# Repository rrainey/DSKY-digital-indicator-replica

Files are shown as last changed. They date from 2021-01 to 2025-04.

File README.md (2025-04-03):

# DSKY Digital Panel Replica

This is a scale functional replica of the Digital Indicator panel for the Apollo Guidance Computer. It is
designed to be part of a larger replica of the Display and Keyboard (DSKY) module of the AGC.

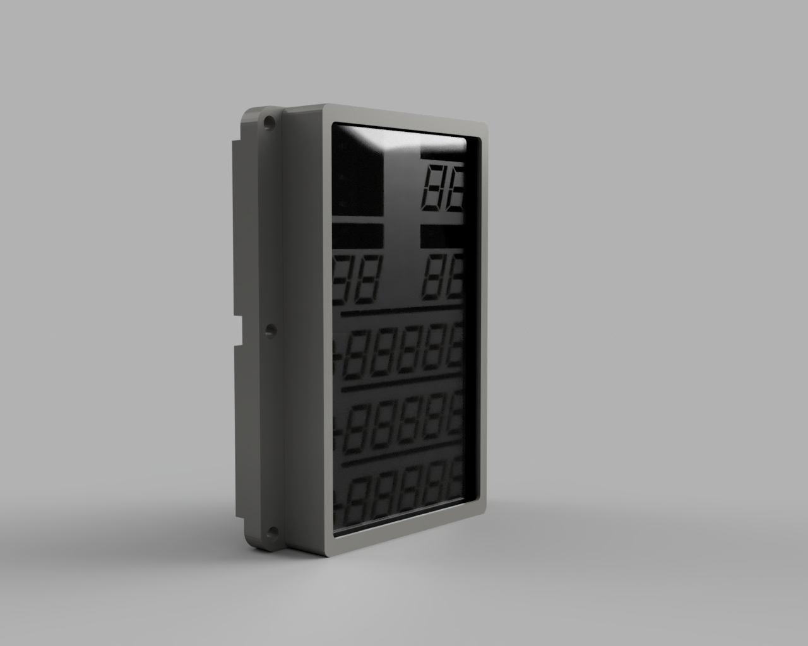
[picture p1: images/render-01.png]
See through view


This project is composed of these component subfolders:

* **artwork** - artwork to be printed or silk-screened onto the glass/acrylic cover.

* **pcb** - KiCad 9 project for the controller PCB design.

* **firmware** - Arduino-based controller firmware.  This module is designed to be controlled via the USB serial interface.

* **hardware** - 3D-printable frame components designed using Fusion 360. STEP and Fusion source files available. Hardware models used in thie replica were derived from models that are part of in the [AGC Mechanical CAD project](https://github.com/rrainey/agc-mechanical-cad).

## Bill of Materials

|  Part | Grainger Part | MFR Part  | QTY | Description |
|---|:---:|---|:-----:|---|
|  M2.5-0.45 Brass Insert| [1GNL7](https://www.grainger.com/product/Heat-Set-Insert-M2-5-0-45-1GNL7?searchQuery=1GNL7&searchBar=true) |  TH-M25-SV-PK100 | 4 | Brass inserts (sold as 100 pack) |
|  M2.5 x 6mm Screw | [6HB66](https://www.grainger.com/product/Machine-Screw-M2-5-Thread-6HB66) |  MPFD025060-100P1 | 4 | Machine screw: M2.5 Thread Size, 6 mm Lg, Steel, Zinc Plated, Flat, Phillips, Metric (sold as 100 pack) |
| Body | - | - | 1 | 3D Printable part |
| Retainer | - | - | 1 | 3D Printable part |
| Light Guide | - | - | 1 | CNC or 3D Printable part |
| PCB to Light Guide Adapter | - | - | 1 | 3D Printable part |
| Indicator face | - | - | 1 | Paper Printable part |

Models for all printable parts are located in the hardware subfolder.

## Interfaces

* USB 2.0 Micro-B port
* J-LINK-compatible SWD debugging interface (10-pin header)
* Power: +3.3VDC via a 4-pin header (2.1A maximum (estimated; software limited to 0.5A))

## Printed Circuit Board

Summary below. You will find more detailed notes in the [./pcb folder](./pcb/PCB-NOTES.md).

As of March 2025, V7 of the PCB design is current. Gerber and component placement files -- all generated by KiCad 7, are included in this repository.  [PCBWay](https://pcbway.com) generously sponsored this version of the project. If you are building one of these boards, you should consider them for either PCB fabrication or full-up PCB assembly.

I often use a solder reflow oven in my shop. I used PCBWay for full PCBA services on this latest version, but with the earlier boards - I assembled them myself using a [two step process](https://www.instructables.com/Making-double-side-boards-in-reflow-oven/) to first reflow the back (LED) side using Sn63/Pb37 paste, then reflow the front side using a lower temperature solder paste (Bi57Sn42Ag1).  

## Painting

The original NASA drawings for all variants of this component, [1006387D for example,](https://archive.org/stream/apertureCardBox439Part2NARASW_images#page/n409/mode/1up) point to [this NASA paint specification [1008809-1]](https://archive.org/stream/apertureCardBox443NARASW_images#page/n504/mode/1up). It states [FED-STD 36231](http://federalstandard595.com/36231/) as the external color of the unit.  Good quality historial photos (examples [here](https://www.icollector.com/Apollo-CM-DSKY_i21861898) and [here](http://nassp.sourceforge.net/wiki/File:DSKY.jpg)) seem to imply a slightly different shade of gray, though. 

I may custom mix using Nazdar pigments, or I might simply use [an aircraft-grade epoxy premix](https://www.skygeek.com/deft-01-series-epoxy-topcoat-gray-36231-mil-prf-227750g.html) of FS36231. For now, I am simply using Krylon brand [Ultra Matte Finish - 4102 Misty Gray](https://www.google.com/search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) paint.

## Credits and Related Projects

This project is inspired by work by Ben Krasnow creating a DSKY Electroluminescent Panel replica. You'll
find information about that project in [this Applied Science video](https://www.youtube.com/watch?v=Z2o_Sp2-aBo) by Ben. Like Ben's E/L display, this project is driven by an AT SAMD21 microcontroller chip; the same chip is used in the multiple Adafruit microcontroller boards, including the Adafruit Trinket M0.

## DSKY Digital Indicator License

Creative Commons Attribution/Share-Alike, all text above must be included in any redistribution. See license.txt for additional details.

## My Background

My name is Riley Rainey. I'm a software developer by profession. I spent a number of years building aerospace simulations as my day job.

## Getting Support

There's no official support available, but you can [leave comments or create an issue](https://github.com/rrainey/DSKY-digital-indicator-replica/issues) in this GitHub project.

  
This work is licensed under a [Creative Commons Attribution-ShareAlike 4.0 International License](http://creativecommons.org/licenses/by-sa/4.0/).

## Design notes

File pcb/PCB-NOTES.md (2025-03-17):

# PCB Fabrication and Assembly Notes

V7 of the PCB is the current version.  PCBWay generously offered to sponsor me on this latest version of the board. I supplied these parameters during the PCB manufacturing process:

| Parameter | Value |
|---|---|
| Material	| FR-4 TG150 |
| Size	| 105.5 x 63.5 mm |
| Layers |	4 |
| Thickness	| 1.6 mm	|
| Min Track/Spacing	| 8/8mil |
| Min Hole Size	 | 0.3 mm	 |
| Solder Mask	| Green	|
| Silkscreen	| White |
| Surface Finish |	ENIG - Immersion gold 1U"
| Via Process	| Tenting vias |
| Finished Copper	(outer layers) | 2 oz Cu |
| Inner Copper	| 1 oz Cu |	
| Gold Fingers	| No	|
| "HASL"to"ENIG" |	No |

If you are planning to assemble the board yourself, I'd suggest using a 0.1mm stainless steel solder stencil along with Type4 or Type 5 solder paste.  I did just that in my early prototypes and, given the small footprint of the TI LED driver ICs, this made laying down the solder for the reflow process much more reliable.

## Assembly

I used a reflow oven to solder components to the boards. I expect it would be difficult to hand solder the TI ICs. 

I populated the front (IC component) side of the board first using Pb 63/Sn 37 solder paste. I used low-temperature Bi/Sn solder for the back (LED) side.  This allowed me to used a lower temperature reflow profile for the back -- insuring the front components remained in-place during the reflow of the second side.

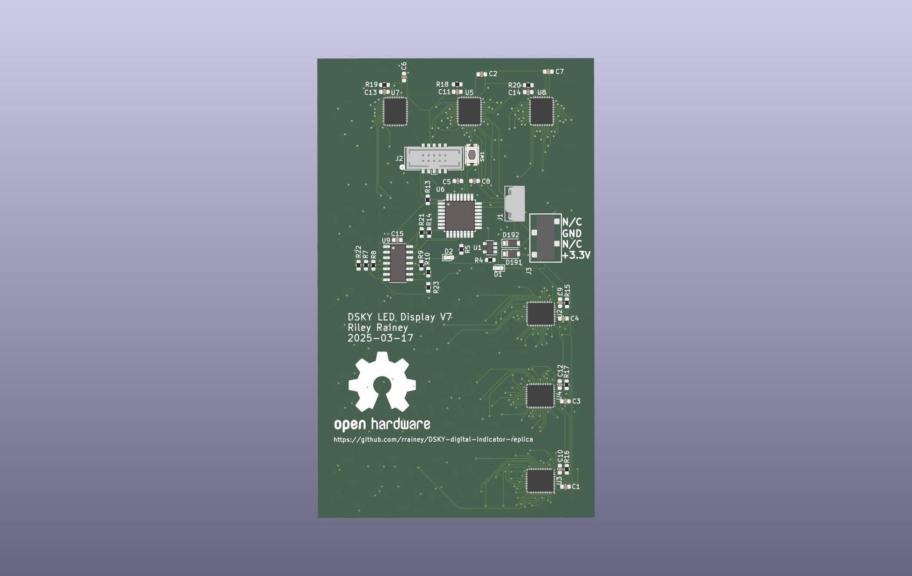
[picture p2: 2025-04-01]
images/DSKY_led_display.png

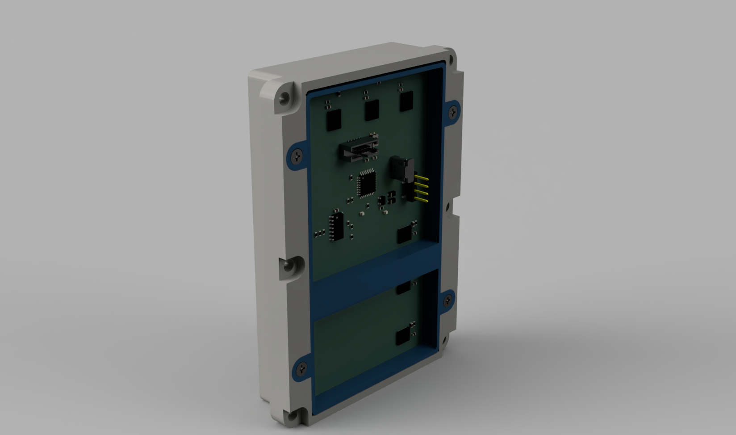
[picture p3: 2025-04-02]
images/render-02.png

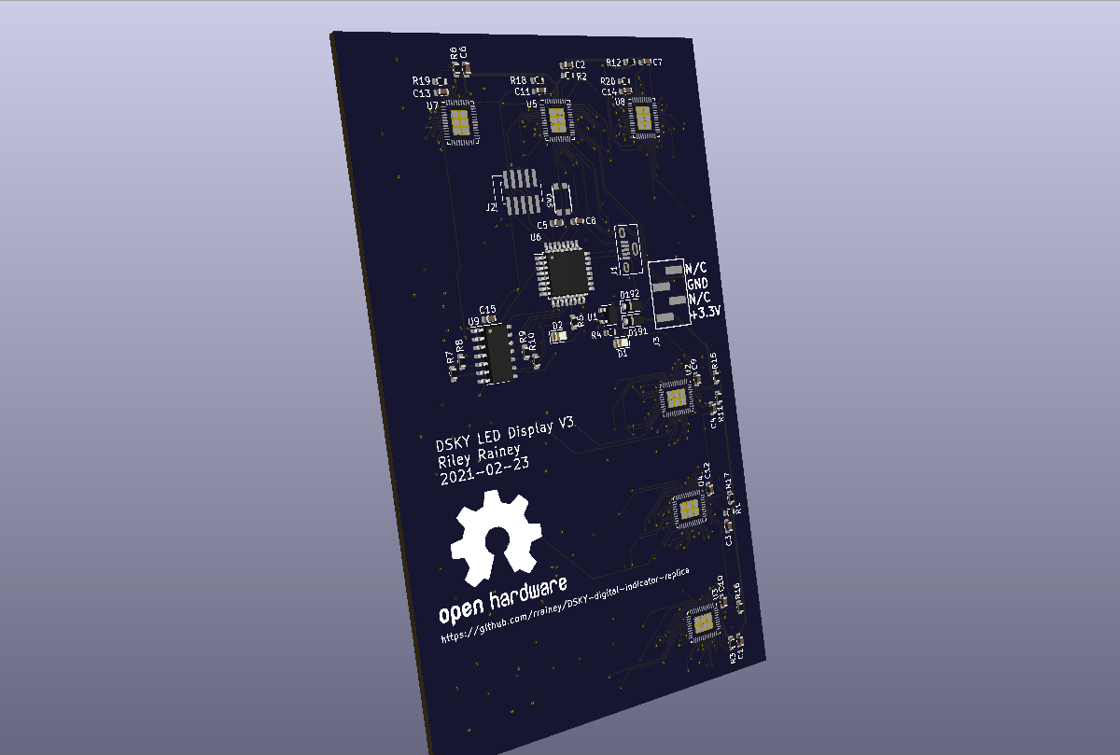
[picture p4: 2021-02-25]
images/pcb-v3-3d-front.PNG

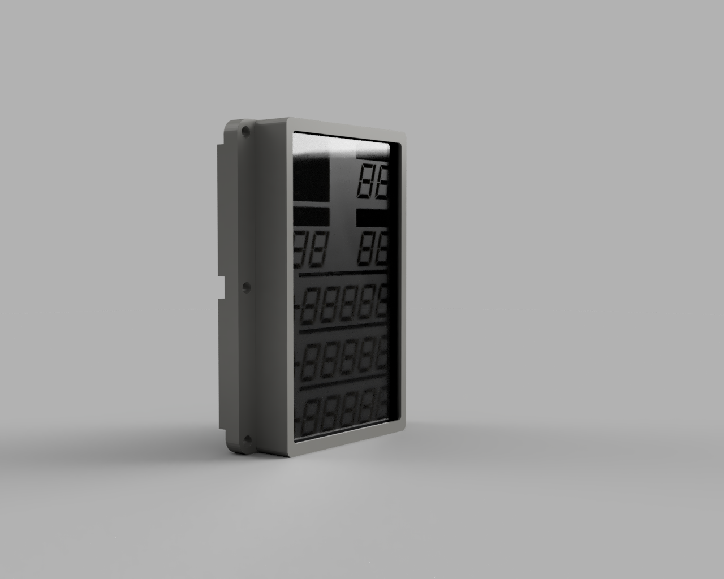
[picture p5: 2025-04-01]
images/render-00.png

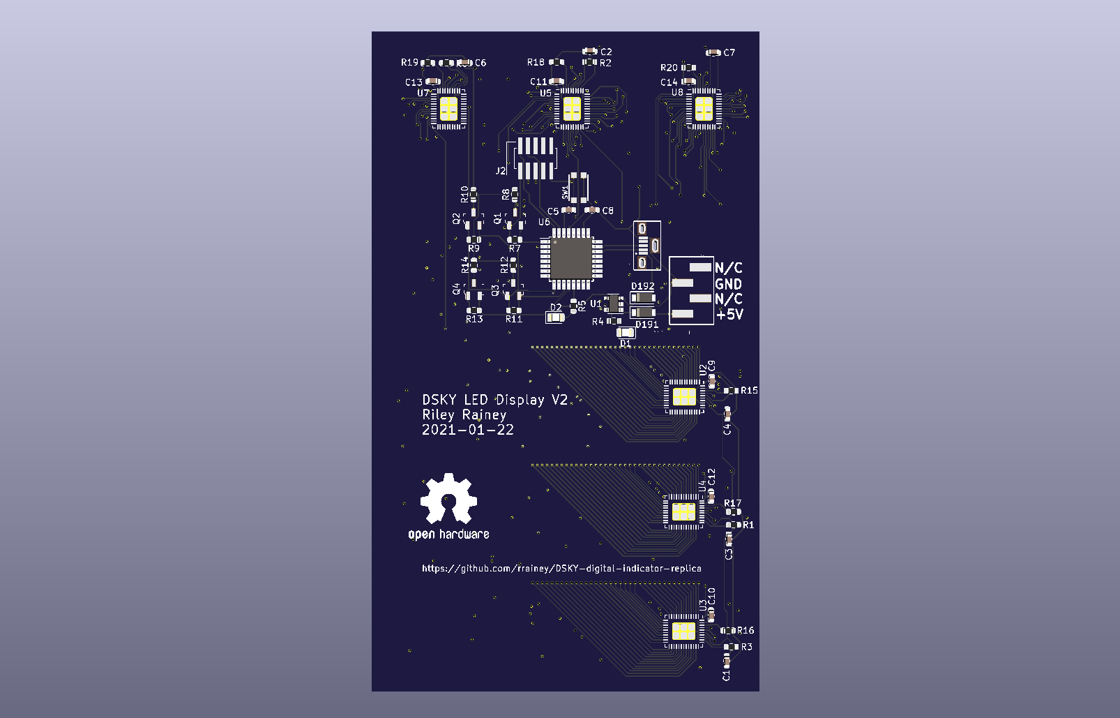
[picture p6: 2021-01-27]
images/pcb-v2-front.PNG

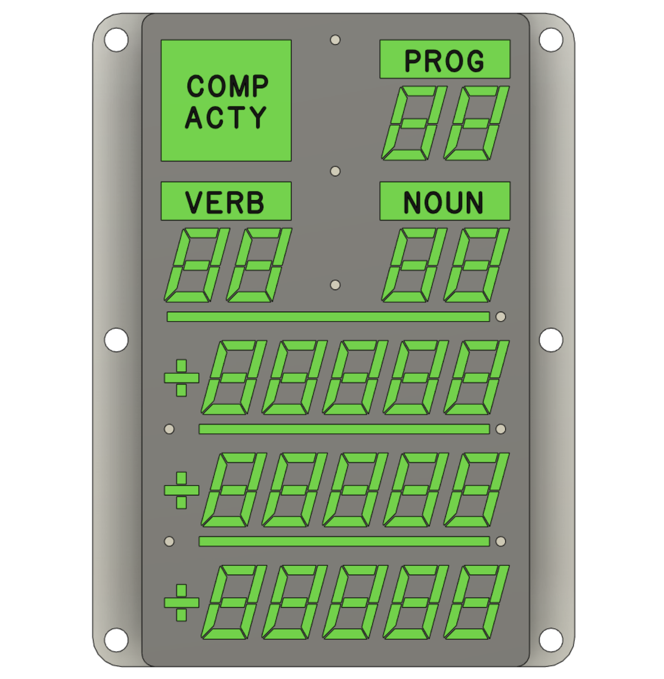
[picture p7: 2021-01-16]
images/intro-01.PNG

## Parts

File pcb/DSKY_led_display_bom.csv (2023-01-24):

Reference | Quantity | Value | Footprint | Datasheet | Description | Digi-Key_PN | Field4 | Field5 | Field6 | Field7 | Field8
C5 C15 | 2 | 10 uF | Capacitor_SMD:C_0603_1608Metric | ~ | CAP CER 10UF 25V X5R 0603 | 311-3494-1-ND
C1 C2 C3 C4 C6 C7 C8 C9 C10 C11 C12 C13 C14 | 13 | 1 uF | Capacitor_SMD:C_0603_1608Metric | ~ | CAP CER 1UF 25V X7R 0603 | 399-C0603C105K3RAC7411CT-ND
D1 | 1 | PWR LED | LED_SMD:LED_0805_2012Metric | http://www.inolux-corp.com/datasheet/SMDLED/Mono%20Color%20Top%20View/IN-S85AT%20Series_V1.1.pdf | LTST-C190GKT ED GREEN CLEAR CHIP SMD
D191 D192 | 2 | B0540W | Diode_SMD:D_SOD-123F | ~ | DIODE SCHOTTKY 40V 500MA SOD123
D2 | 1 | red | LED_SMD:LED_0805_2012Metric | http://www.inolux-corp.com/datasheet/SMDLED/Mono%20Color%20Top%20View/IN-S85AT%20Series_V1.1.pdf | LTST-S270KRKT LED RED CLEAR CHIP SMD R/A
D3 D4 D5 D6 D7 D8 D9 D10 D11 D12 D13 D14 D15 D16 D17 D18 D19 D20 D21 D22 D23 D24 D25 D26 D27 D28 D29 D30 D31 D32 D33 D34 D35 D36 D37 D38 D39 D40 D41 D42 D43 D44 D45 D46 D47 D48 D49 D50 D51 D52 D53 D54 D55 D56 D57 D58 D59 D60 D61 D62 D63 D64 D65 D66 D67 D68 D69 D70 D71 D72 D73 D74 D75 D76 D77 D78 D79 D80 D81 D82 D83 D84 D85 D86 D87 D88 D89 D90 D91 D92 D93 D94 D95 D96 D97 D98 D99 D100 D101 D102 D103 D104 D105 D106 D107 D108 D109 D110 D111 D112 D113 D114 D115 D116 D117 D118 D119 D120 D121 D122 D123 D124 D125 D126 D127 D128 D129 D130 D131 D132 D133 D134 D135 D136 D137 D138 D139 D140 D141 D142 D143 D144 D145 D146 D147 D148 D149 D150 D151 D152 D153 D154 D155 D156 D157 D158 D159 D160 D161 D162 D163 D164 D165 D166 D167 D168 D169 D170 D171 D172 D173 D174 D175 D176 D177 D178 D179 D180 D181 D182 D183 D184 D185 D186 D187 D188 D189 D190 | 188 | IN-S85ATG | LED_SMD:LED_0805_2012Metric | http://www.inolux-corp.com/datasheet/SMDLED/Mono%20Color%20Top%20View/IN-S85AT%20Series_V1.1.pdf | LED GREEN CLEAR 0805 SMD | 1830-1079-1-ND
J1 | 1 | 105133-0001 | led-project:MOLEX_105133-0001 | 0.50 USD | CONN RCPT USB2.0 MICRO B SMD | WM9734CT-ND | None | 105133-0001 | Good | Molex | Conn Micro USB Type B RCP 5 POS 0.65mm Solder RA SMD 5 Terminal 1 Port Embossed T/R
J2 | 1 | 3221-10-0300-00-TR | led-project:3221-10-0300-00-TR | http://www.cnctech.us/pdfs/3221-XX-0300-00-TR_.pdf | CONN HEADER SMD 10POS 1.27MM | 1175-2649-1-ND
J3 | 1 | TSM-104-01-L-SV | led-project:TSM-104-01-L-SV |  | CONN HEADER SMD 4POS 2.54MM | SAM13287CT-ND
R13 | 1 | 0K | Resistor_SMD:R_0603_1608Metric | ~ | RES SMD 1K OHM 5% 1/10W 0603 | 541-4.7KGCT-ND
R15 R16 R17 R18 R19 R20 | 6 | 3.65K | Resistor_SMD:R_0603_1608Metric | ~ | RES SMD 3.65K OHM 1% 1/3W 0603 | 541-3.65KSCT-ND
R4 R5 | 2 | 1.5K | Resistor_SMD:R_0603_1608Metric | ~ | RES SMD 1.5K OHM 1% 1/10W 0603 | 541-1781-1-ND
R7 R8 R9 R10 R14 R21 R22 R23 | 8 | 1K | Resistor_SMD:R_0603_1608Metric | ~ | RES SMD 4.7K OHM 5% 1/10W 0603 | 541-4.7KGCT-ND
SW1 | 1 | KMR241NG | led-project:BTN_KMR2_4.6X2.8 |  | SWITCH TACTILE SPST-NO 0.05A 32V
U1 | 1 | AP2204K-3.3 | Package_TO_SOT_SMD:SOT-23-5 | https://www.diodes.com/assets/Datasheets/AP2204.pdf | IC REG LINEAR 3.3V 150MA SOT23-5 | AP2204K-3.3TRG1DICT-ND
U2 U3 U4 U5 U7 U8 | 6 | LP5036 | Package_DFN_QFN:VQFN-46-1EP_5x6mm_P0.4mm_EP2.8x3.8mm | http://www.ti.com/lit/ds/symlink/lp5036.pdf | LED DRIVER | 296-LP5036RJVRCT-ND
U6 | 1 | ATSAMD21E18A-A | Package_QFP:TQFP-32_7x7mm_P0.8mm | http://ww1.microchip.com/downloads/en/DeviceDoc/SAM_D21_DA1_Family_Data%20Sheet_DS40001882E.pdf | IC MCU 32BIT 256KB FLASH 32TQFP | ATSAMD21E18A-AU-ND
U9 | 1 | TCA9543ADR | Package_SO:SOIC-14_3.9x8.7mm_P1.27mm

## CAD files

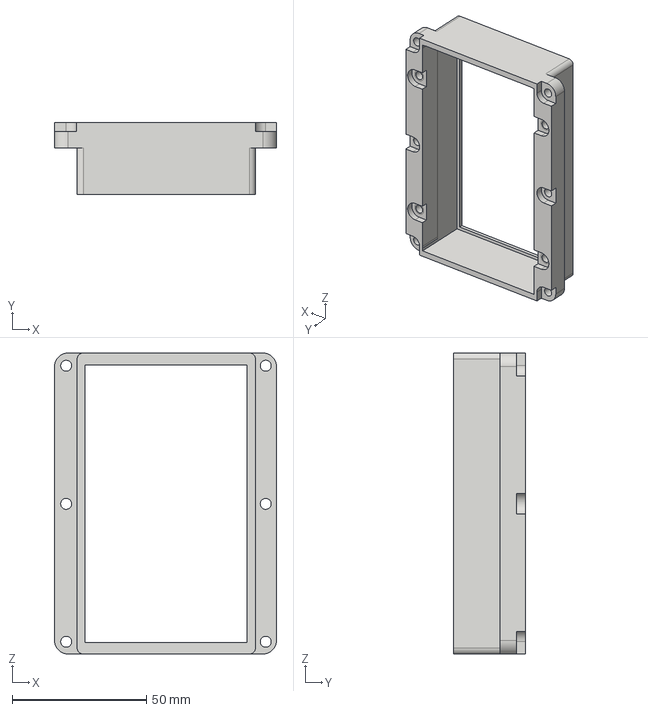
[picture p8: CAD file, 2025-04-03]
hardware/Body.step
82.8 x 26.7 x 112.3 mm

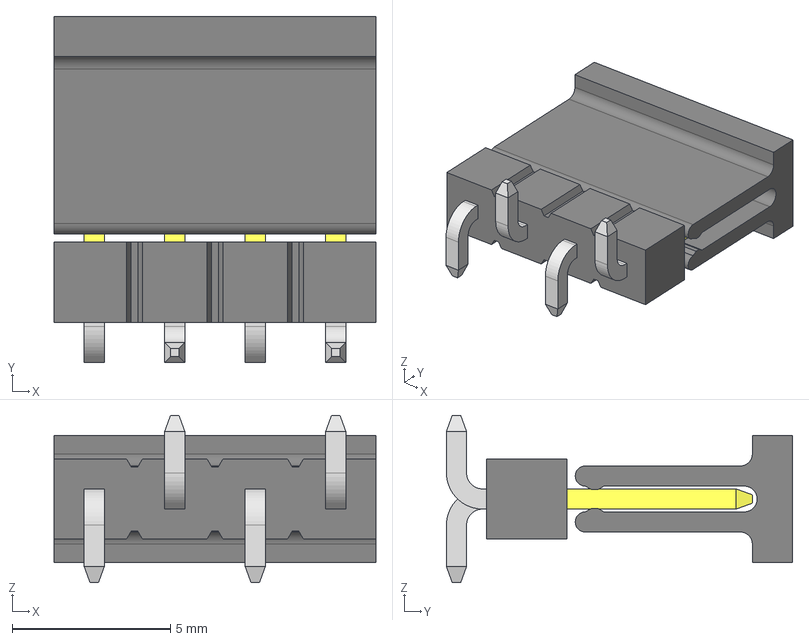
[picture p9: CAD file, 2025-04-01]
pcb/models/tsm-104-01-l-sv-p-tr.stp
10.2 x 10.9 x 5.28 mm

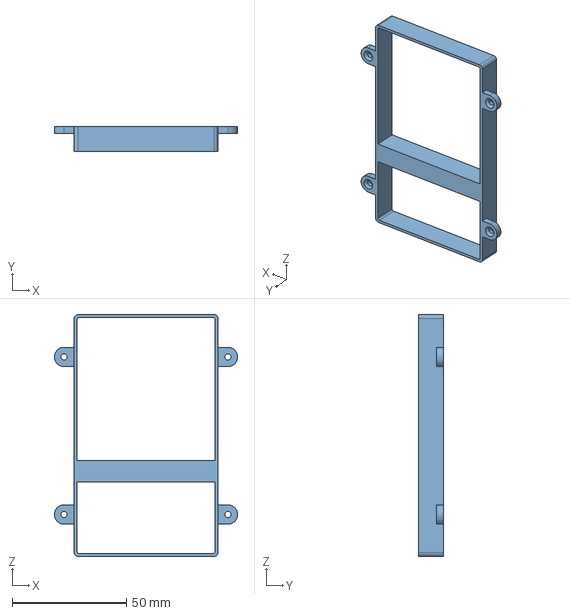
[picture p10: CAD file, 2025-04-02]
hardware/Retainer.step
80.3 x 10.9 x 106.1 mm

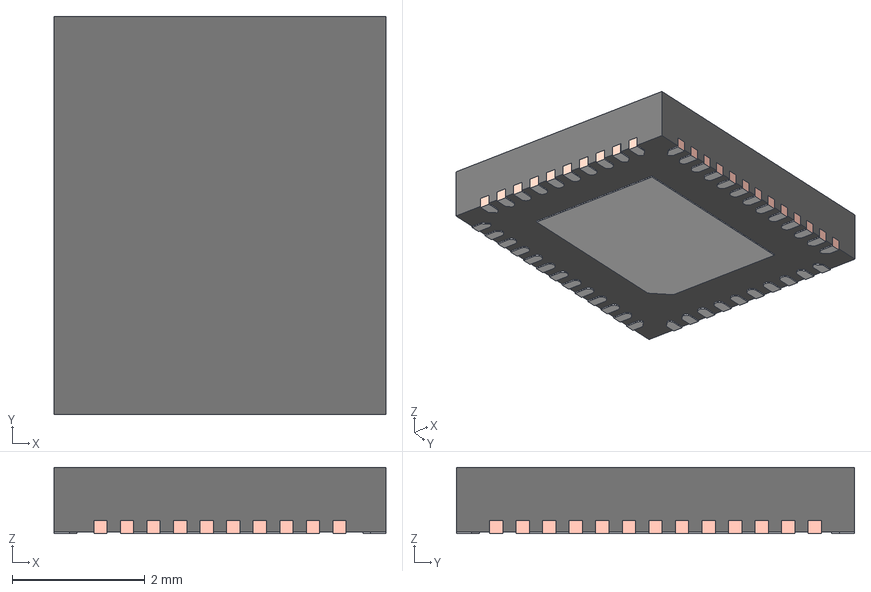
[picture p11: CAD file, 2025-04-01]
pcb/models/RJV0046A.stp
5.00 x 6.00 x 1.00 mm
BODY-QFN
FRAME-RJV0046A
PIN1-ID

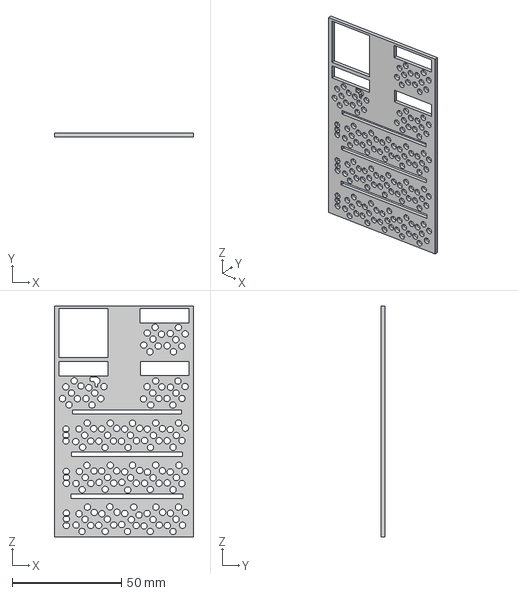
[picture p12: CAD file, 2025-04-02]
hardware/PCB to Light-guide adapter.step
63.5 x 1.80 x 105.5 mm

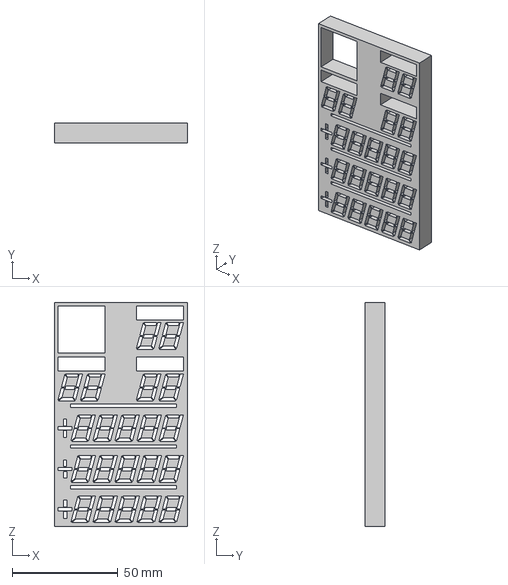
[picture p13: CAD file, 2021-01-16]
hardware/LED-light-guide.step
63.0 x 9.52 x 106.0 mm

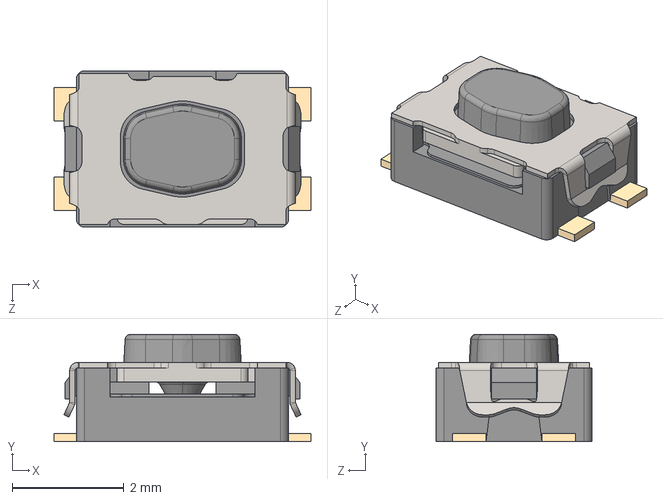
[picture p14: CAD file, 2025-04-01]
pcb/models/KMR221NG_LFS.stp
4.60 x 1.92 x 2.80 mm

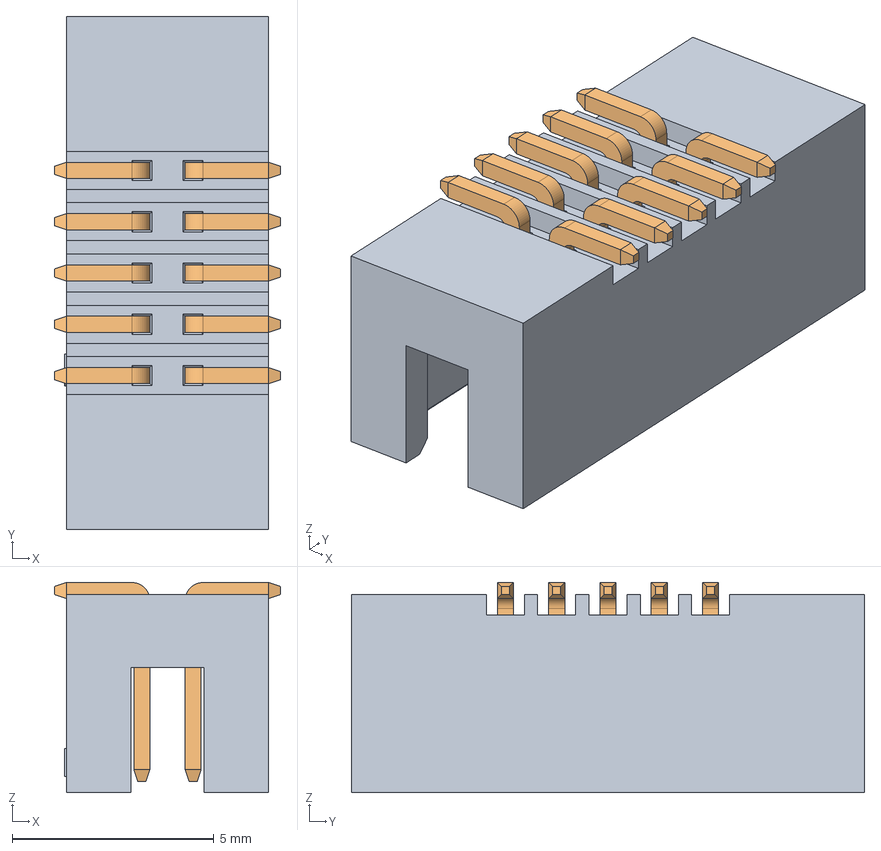
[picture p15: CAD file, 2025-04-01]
pcb/models/3221-10-0300-00 3D.STP
5.60 x 12.7 x 5.20 mm
801-2195-10-K
2195SM-PIN x 10

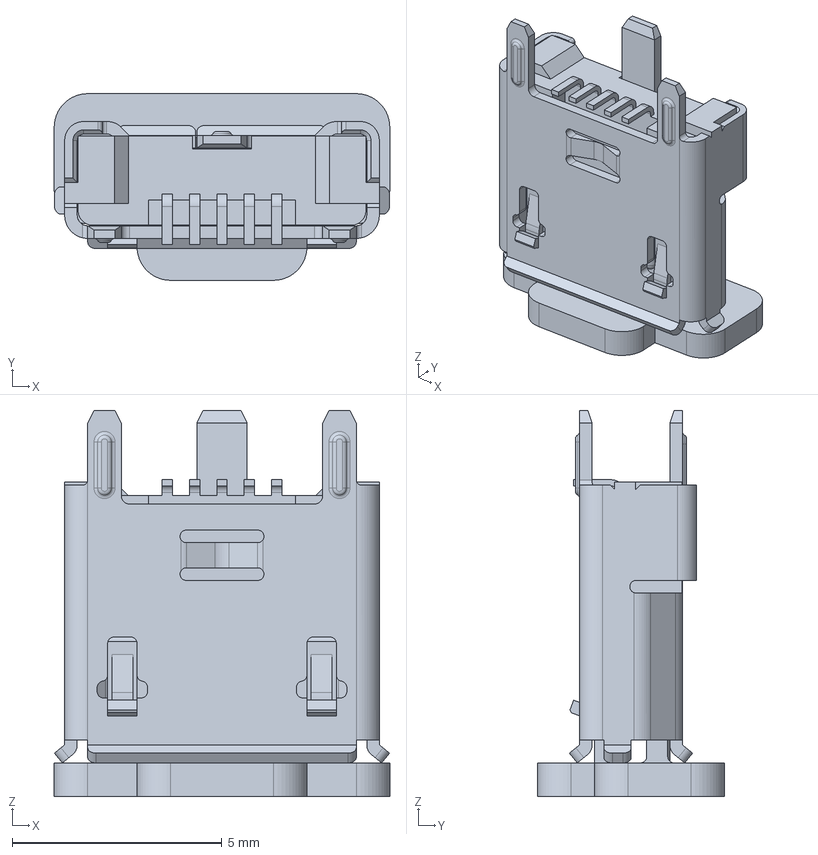
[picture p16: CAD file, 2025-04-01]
pcb/models/1051330001.stp
8.00 x 4.45 x 9.20 mm

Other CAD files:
hardware/LED-light-guide.f3d

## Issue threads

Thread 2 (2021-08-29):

V4 board is about 2.5mm too tall

rrainey, 2021-08-29:
The V4 board (along with all predecessors) is just a bit too tall to fit in the original EL Display enclosure.

Solution: cut V4 boards as needed (1mm off top and 1.5mm off bottom). Add a V5 board with proper cuts.

Closed 2025-03-17.

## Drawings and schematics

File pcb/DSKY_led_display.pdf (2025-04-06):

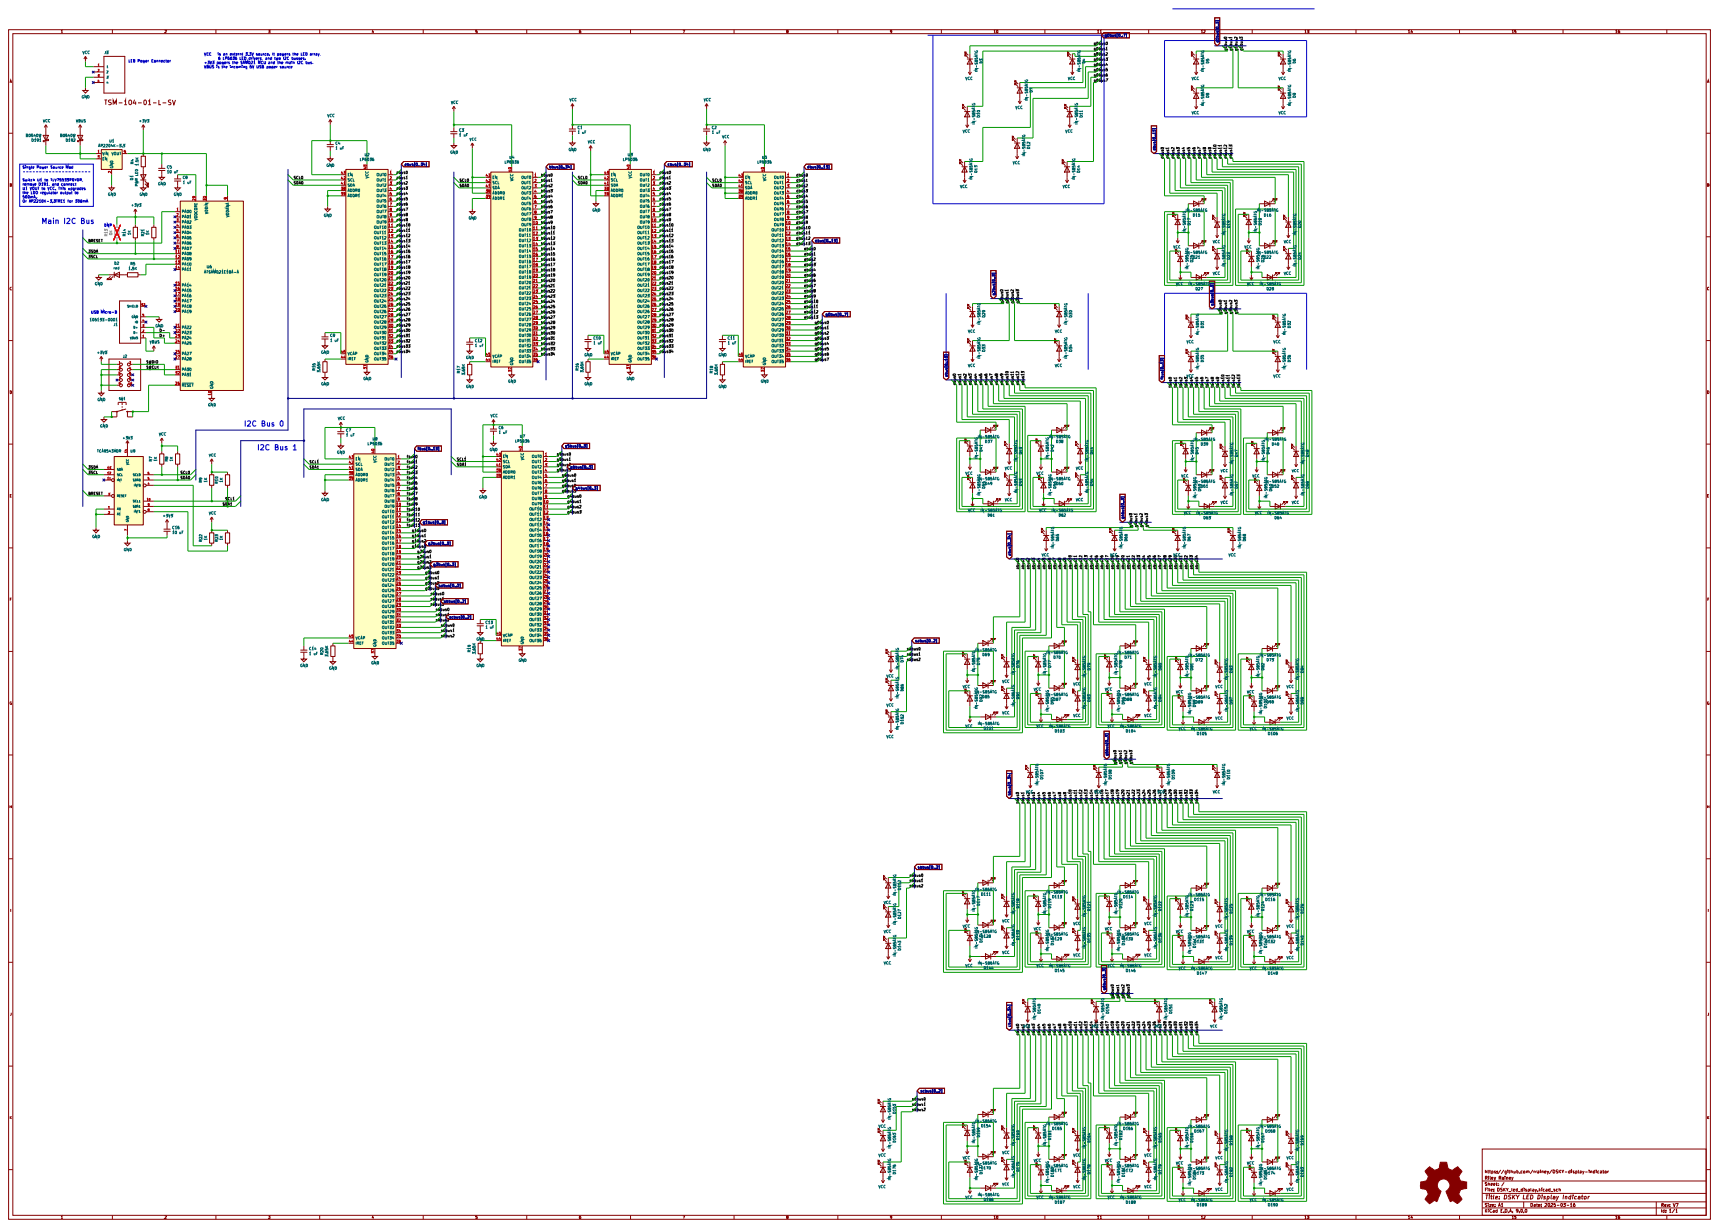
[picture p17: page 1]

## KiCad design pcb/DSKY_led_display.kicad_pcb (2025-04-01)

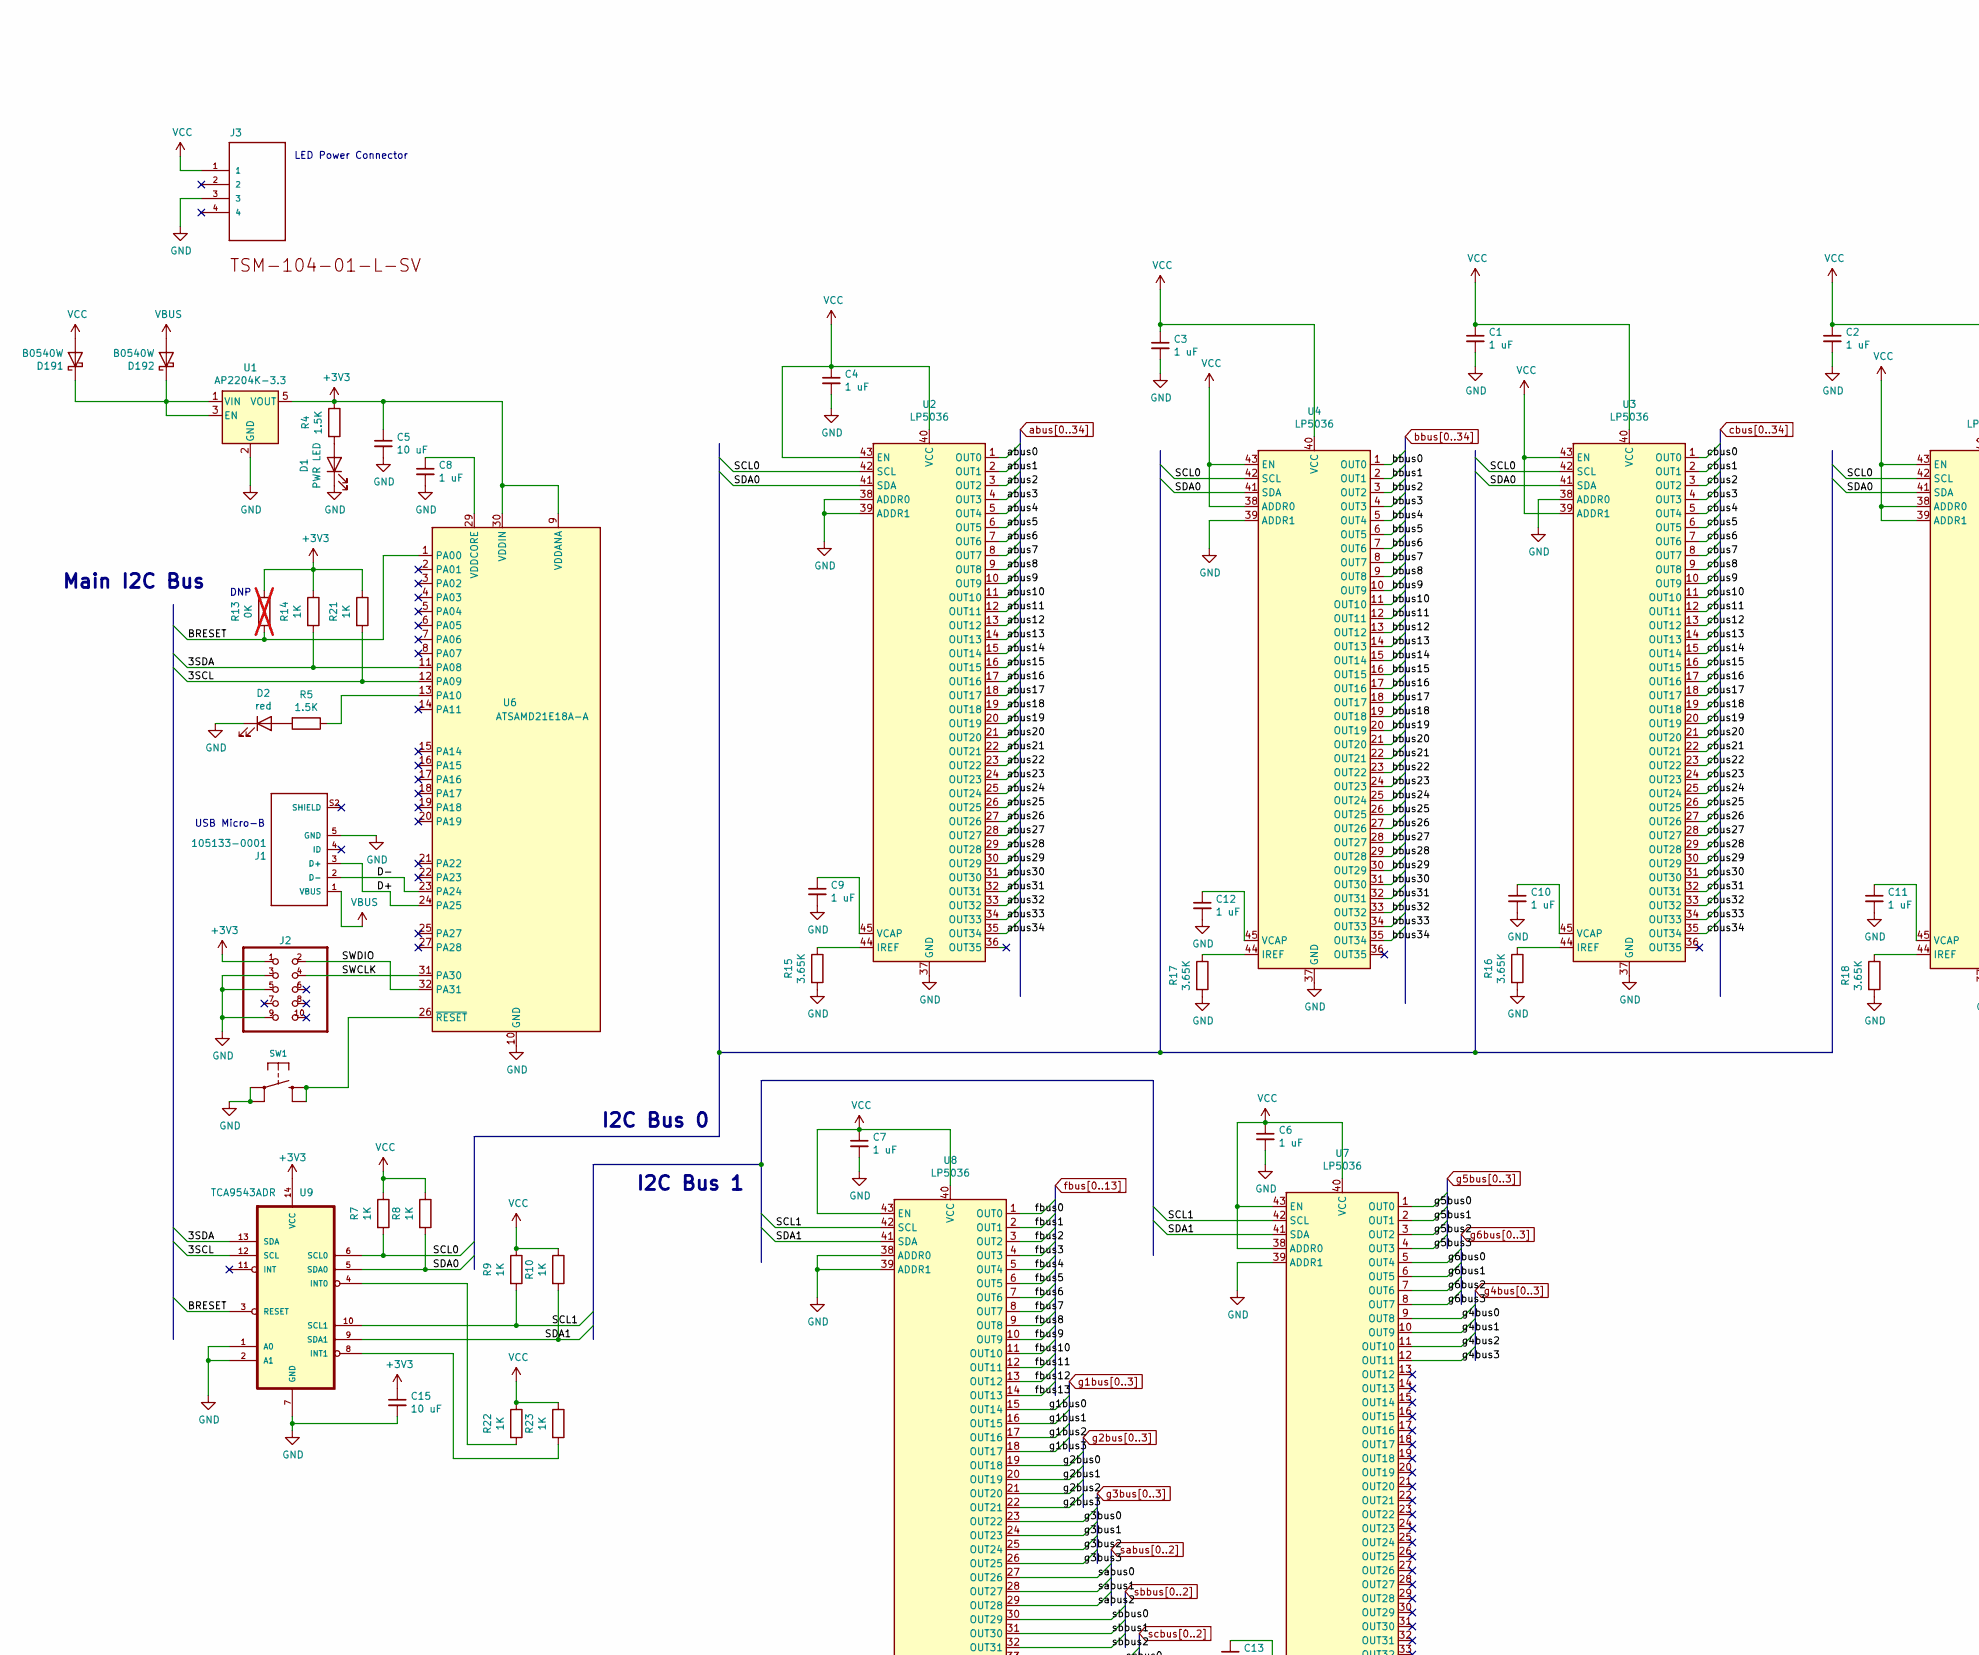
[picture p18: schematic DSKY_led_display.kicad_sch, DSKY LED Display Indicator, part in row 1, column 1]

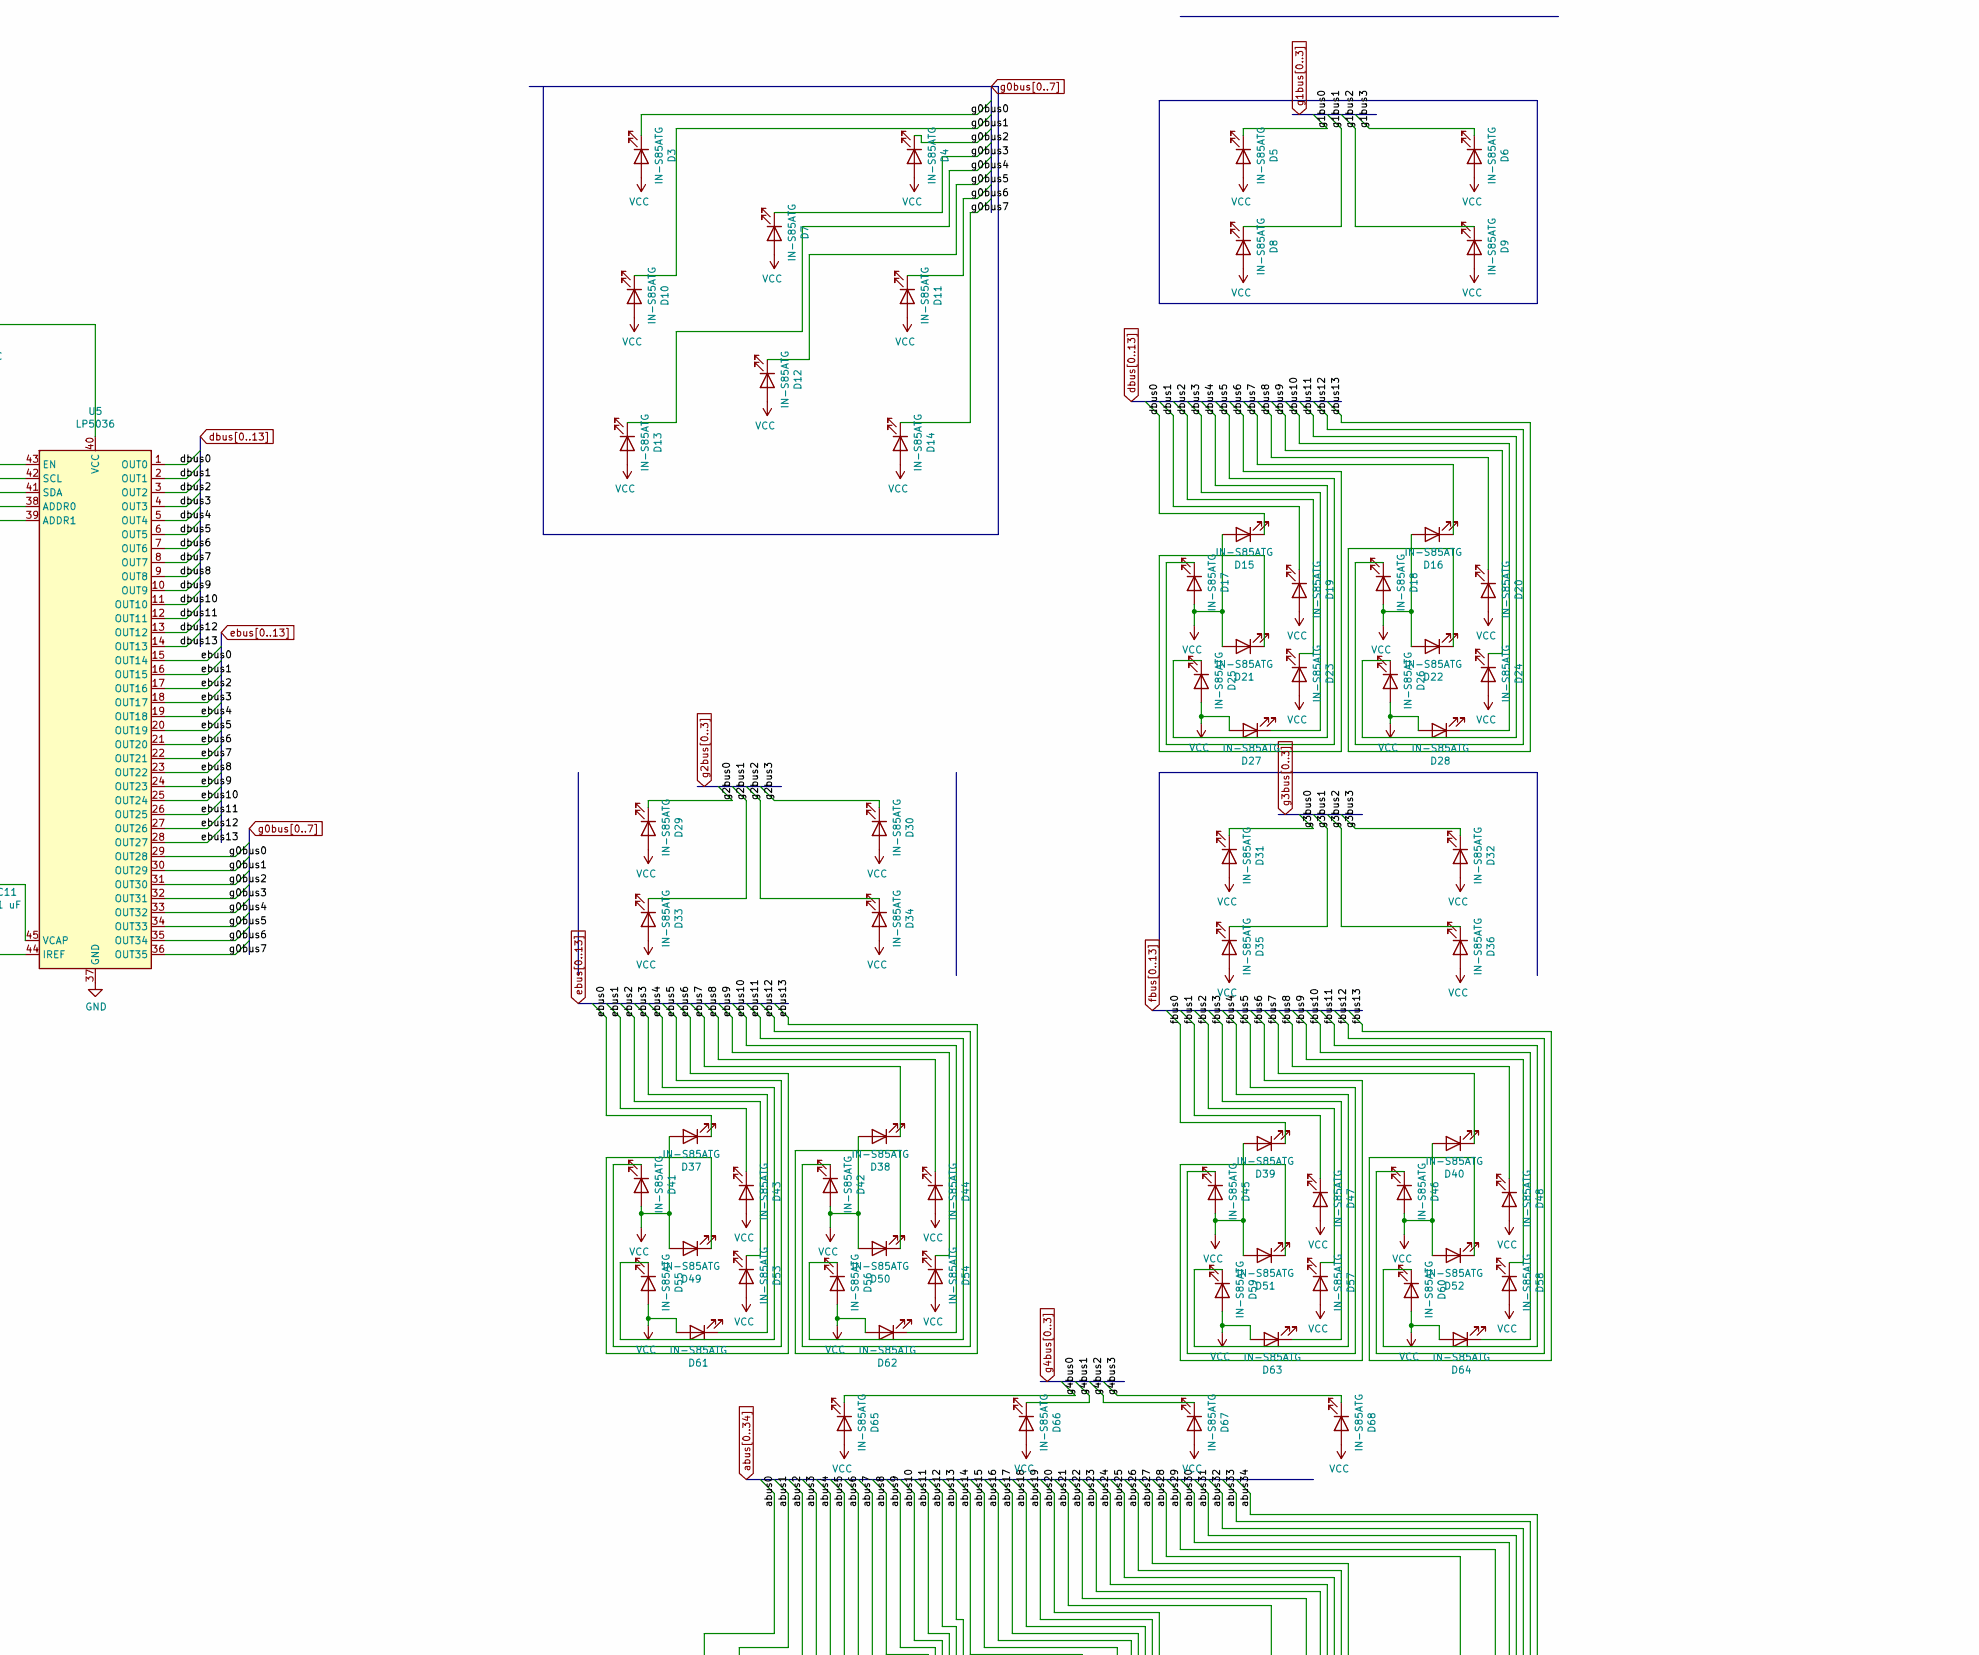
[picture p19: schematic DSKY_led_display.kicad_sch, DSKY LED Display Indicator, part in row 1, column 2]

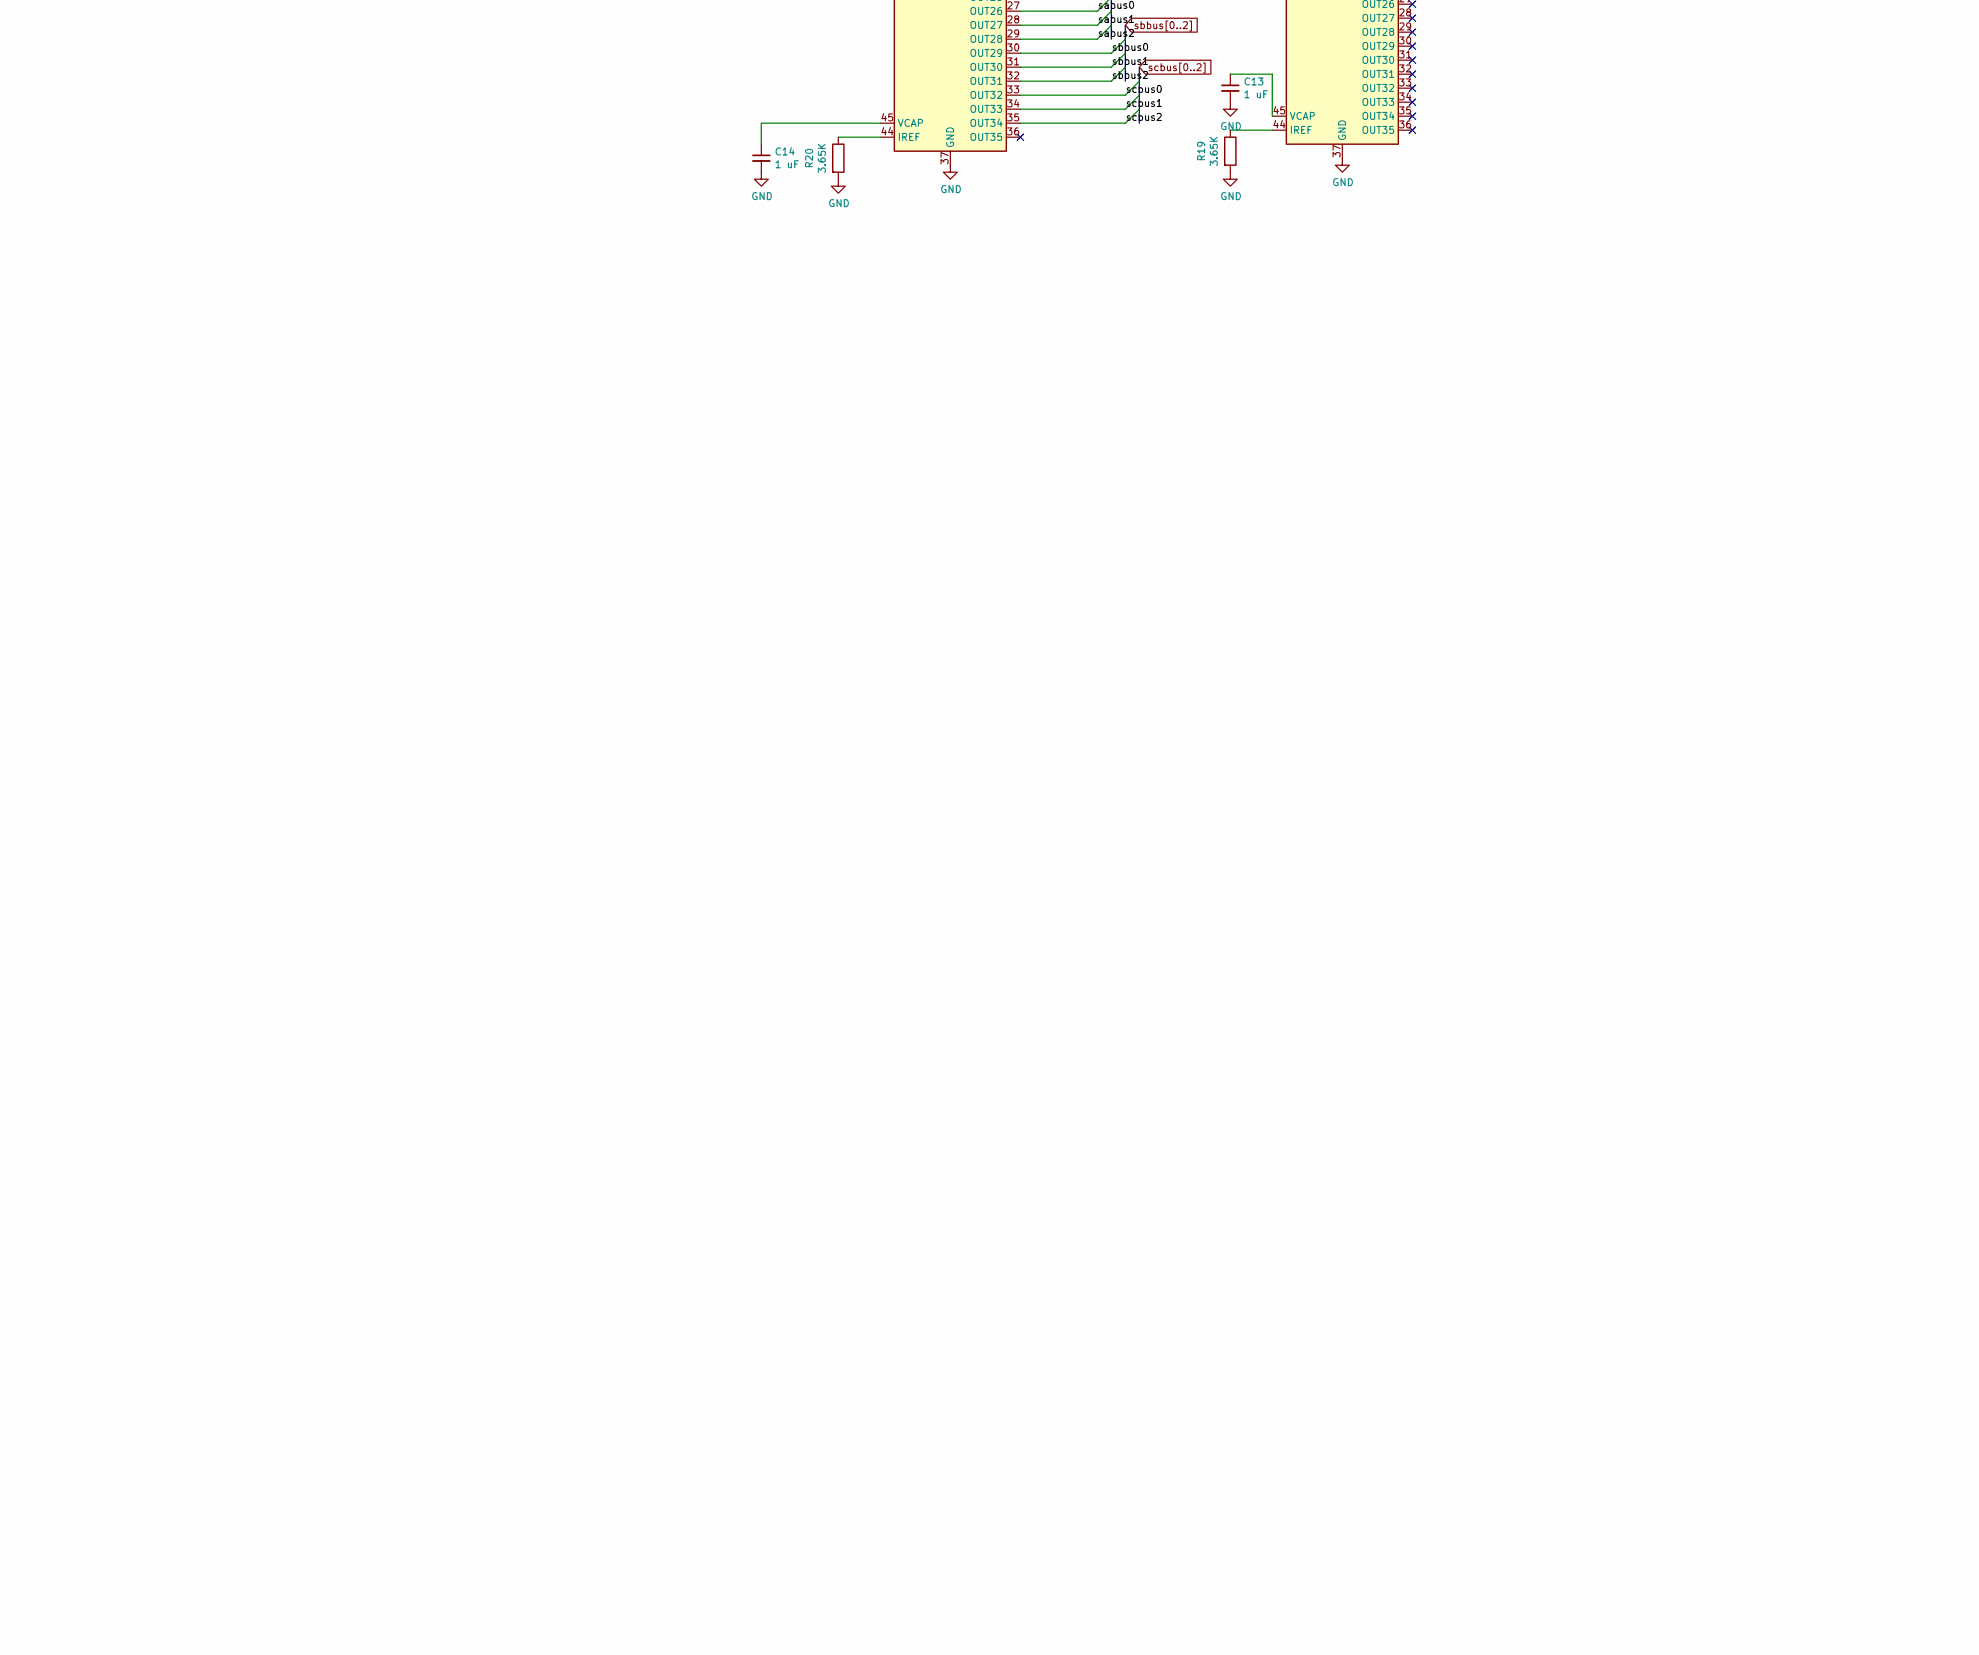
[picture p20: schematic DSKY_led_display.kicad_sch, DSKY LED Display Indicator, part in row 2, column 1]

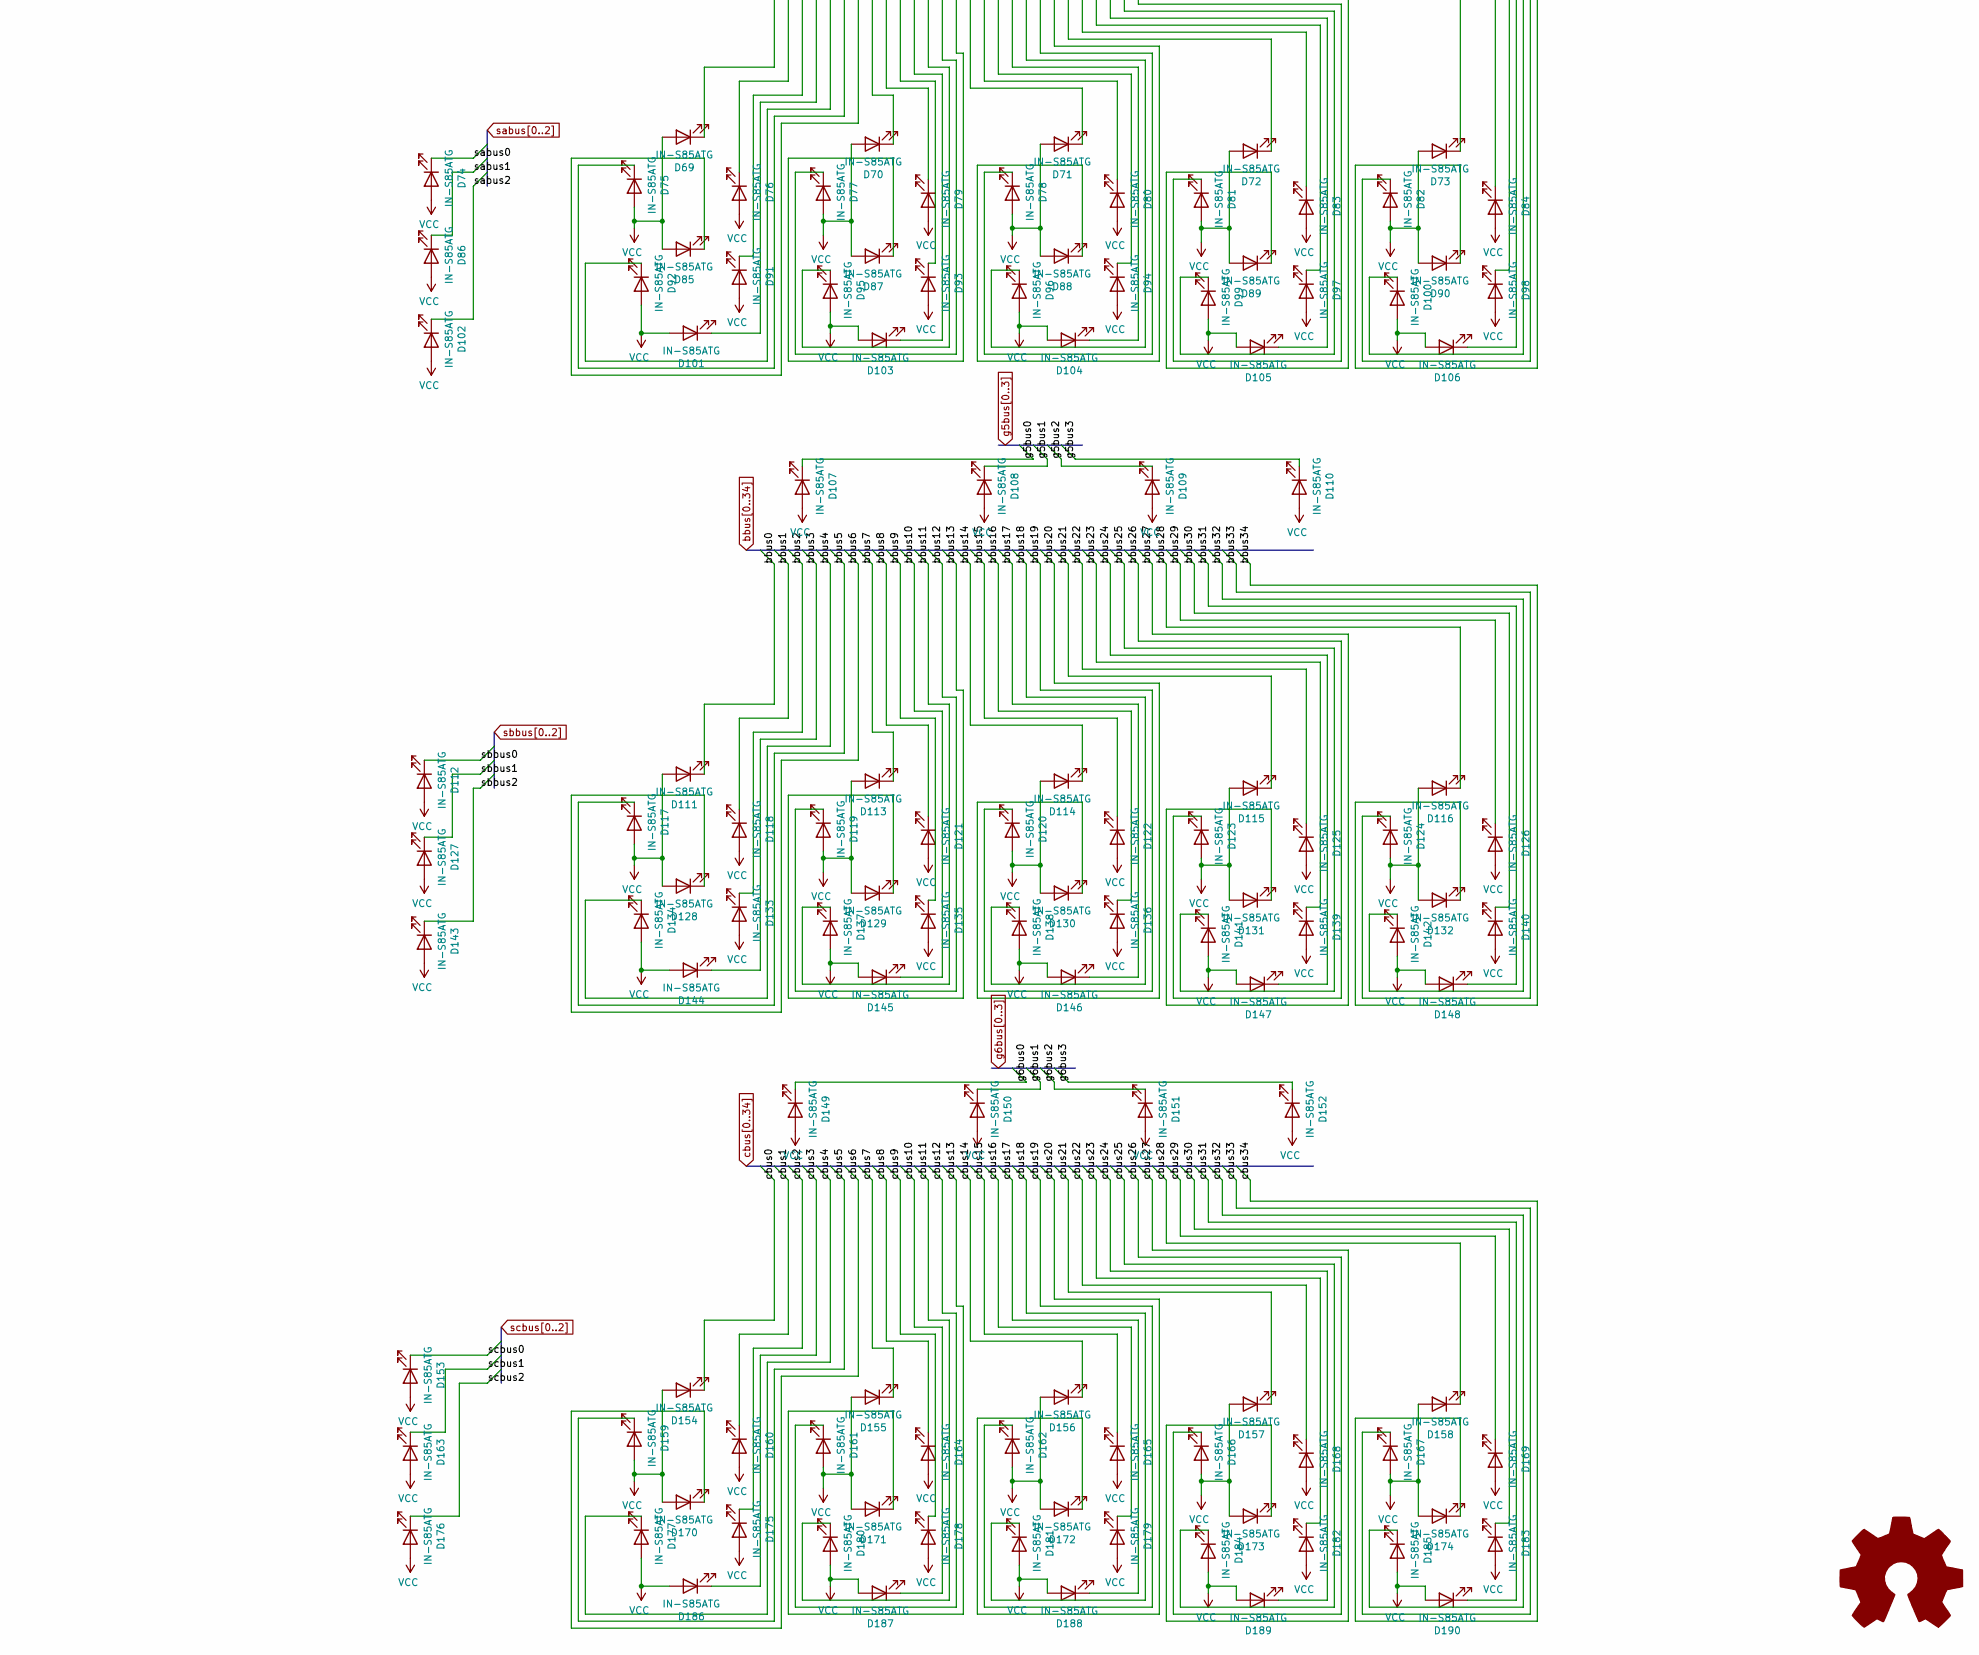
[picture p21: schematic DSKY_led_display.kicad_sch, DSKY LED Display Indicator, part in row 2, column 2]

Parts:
C1, C2, C3, C4, C6, C7, C8, C9, C10, C11, C12, C13, C14: 1 uF; C_0603_1608Metric; Digi-Key_PN 399-C0603C105K3RAC7411CT-ND
C5, C15: 10 uF; C_0603_1608Metric; Digi-Key_PN 311-3494-1-ND
D1: PWR LED; LED_0603_1608Metric; Digi-Key_PN 160-1183-1-ND
D2: red; LED_0603_1608Metric; Digi-Key_PN 732-4978-1-ND
D3, D4, D5, D6, D7, D8, D9, D10, D11, D12, D13, D14, D15, D16, D17, D18, D19, D20, D21, D22, D23, D24, D25, D26, D27, D28, D29, D30, D31, D32, D33, D34, D35, D36, D37, D38, D39, D40, D41, D42, D43, D44, D45, D46, D47, D48, D49, D50, D51, D52, D53, D54, D55, D56, D57, D58, D59, D60, D61, D62, D63, D64, D65, D66, D67, D68, D69, D70, D71, D72, D73, D74, D75, D76, D77, D78, D79, D80, D81, D82, D83, D84, D85, D86, D87, D88, D89, D90, D91, D92, D93, D94, D95, D96, D97, D98, D99, D100, D101, D102, D103, D104, D105, D106, D107, D108, D109, D110, D111, D112, D113, D114, D115, D116, D117, D118, D119, D120, D121, D122, D123, D124, D125, D126, D127, D128, D129, D130, D131, D132, D133, D134, D135, D136, D137, D138, D139, D140, D141, D142, D143, D144, D145, D146, D147, D148, D149, D150, D151, D152, D153, D154, D155, D156, D157, D158, D159, D160, D161, D162, D163, D164, D165, D166, D167, D168, D169, D170, D171, D172, D173, D174, D175, D176, D177, D178, D179, D180, D181, D182, D183, D184, D185, D186, D187, D188, D189, D190: IN-S85ATG; LED_0805_2012Metric; Digi-Key_PN 1830-1079-1-ND
D191, D192: B0540W; D_SOD-123F; Digi-Key_PN 1801-B0540WTR-ND
J1: 105133-0001; MOLEX_105133-0001; Digi-Key_PN WM9734CT-ND
J2: 3221-10-0300-00-TR; Digi-Key_PN 1175-2649-1-ND
J3: TSM-104-01-L-SV; Digi-Key_PN SAM13287CT-ND
R4, R5: 1.5K; R_0603_1608Metric; Digi-Key_PN 541-1781-1-ND
R7, R8, R9, R10, R14, R21, R22, R23: 1K; R_0603_1608Metric; Digi-Key_PN 541-1.0KGCT-ND
R13: 0K; R_0603_1608Metric; not fitted
R15, R16, R17, R18, R19, R20: 3.65K; R_0603_1608Metric; Digi-Key_PN 541-3.65KSCT-ND
SW1: KMR241NG; BTN_KMR2_4.6X2.8; Digi-Key_PN CKN10247TR-ND
U1: AP2204K-3.3; SOT-23-5; Digi-Key_PN AP2204K-3.3TRG1DICT-ND
U2, U3, U4, U5, U7, U8: LP5036; VQFN-46-1EP_5x6mm_P0.4mm_EP2.8x3.8mm; Digi-Key_PN 296-LP5036RJVRCT-ND
U6: ATSAMD21E18A-A; TQFP-32_7x7mm_P0.8mm; Digi-Key_PN ATSAMD21E18A-AU-ND
U9: TCA9543ADR; SOIC-14_3.9x8.7mm_P1.27mm

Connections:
+3V3: C5.1, C15.1, J2.1, R4.1, R13.1, R14.1, R21.1, U1.5 (VOUT), U6.9 (VDDANA), U6.30 (VDDIN), U9.14 (VCC)
/3SCL: R21.2, U6.12 (PA09), U9.12 (SCL)
/3SDA: R14.2, U6.11 (PA08), U9.13 (SDA)
/BRESET: R13.2, U6.1 (PA00), U9.3 (RESET)
/D+: J1.3 (D+), U6.24 (PA25)
/D-: J1.2 (D-), U6.23 (PA24)
/SCL0: R7.2, U2.42 (SCL), U3.42 (SCL), U4.42 (SCL), U5.42 (SCL), U9.6 (SCL0)
/SCL1: R9.2, U7.42 (SCL), U8.42 (SCL), U9.10 (SCL1)
/SDA0: R8.2, U2.41 (SDA), U3.41 (SDA), U4.41 (SDA), U5.41 (SDA), U9.5 (SDA0)
/SDA1: R10.2, U7.41 (SDA), U8.41 (SDA), U9.9 (SDA1)
/SWCLK: J2.4, U6.31 (PA30)
/SWDIO: J2.2, U6.32 (PA31)
GND: C1.2, C2.2, C3.2, C4.2, C5.2, C6.2, C7.2, C8.2, C9.2, C10.2, C11.2, C12.2, C13.2, C14.2, C15.2, D1.1 (K), D2.1 (K), J1.5 (GND), J2.3, J2.5, J2.9, J3.3, R15.2, R16.2, R17.2, R18.2, R19.2, R20.2, SW1.A, SW1.A' (P1), U1.2 (GND), U2.37 (GND), U2.38 (ADDR0), U2.39 (ADDR1), U2.46 (GND), U2.47 (GND), U3.37 (GND), U3.38 (ADDR0), U3.46 (GND), U3.47 (GND), U4.37 (GND), U4.39 (ADDR1), U4.46 (GND), U4.47 (GND), U5.37 (GND), U5.46 (GND), U5.47 (GND), U6.10 (GND), U6.28 (GND), U7.37 (GND), U7.39 (ADDR1), U7.46 (GND), U7.47 (GND), U8.37 (GND), U8.38 (ADDR0), U8.39 (ADDR1), U8.46 (GND), U8.47 (GND), U9.1 (A0), U9.2 (A1), U9.7 (GND)
unnamed: D1.2 (A), R4.2
unnamed: D2.2 (A), R5.2
unnamed: D191.1 (K), D192.1 (K), U1.1 (VIN), U1.3 (EN)
unnamed: SW1.B (S), SW1.B' (S1), U6.26 (~RESET)
unnamed: R15.1, U2.44 (IREF)
unnamed: C9.1, U2.45 (VCAP)
unnamed: R16.1, U3.44 (IREF)
unnamed: C10.1, U3.45 (VCAP)
unnamed: R17.1, U4.44 (IREF)
unnamed: C12.1, U4.45 (VCAP)
unnamed: R18.1, U5.44 (IREF)
unnamed: C11.1, U5.45 (VCAP)
unnamed: R5.1, U6.13 (PA10)
unnamed: C8.1, U6.29 (VDDCORE)
unnamed: R19.1, U7.44 (IREF)
unnamed: C13.1, U7.45 (VCAP)
unnamed: R20.1, U8.44 (IREF)
unnamed: C14.1, U8.45 (VCAP)
unnamed: R22.2, U9.4 (INT0)
unnamed: R23.2, U9.8 (INT1)
VBUS: D192.2 (A), J1.1 (VBUS)
VCC: C1.1, C2.1, C3.1, C4.1, C6.1, C7.1, D3.2 (A), D4.2 (A), D5.2 (A), D6.2 (A), D7.2 (A), D8.2 (A), D9.2 (A), D10.2 (A), D11.2 (A), D12.2 (A), D13.2 (A), D14.2 (A), D15.2 (A), D16.2 (A), D17.2 (A), D18.2 (A), D19.2 (A), D20.2 (A), D21.2 (A), D22.2 (A), D23.2 (A), D24.2 (A), D25.2 (A), D26.2 (A), D27.2 (A), D28.2 (A), D29.2 (A), D30.2 (A), D31.2 (A), D32.2 (A), D33.2 (A), D34.2 (A), D35.2 (A), D36.2 (A), D37.2 (A), D38.2 (A), D39.2 (A), D40.2 (A), D41.2 (A), D42.2 (A), D43.2 (A), D44.2 (A), D45.2 (A), D46.2 (A), D47.2 (A), D48.2 (A), D49.2 (A), D50.2 (A), D51.2 (A), D52.2 (A), D53.2 (A), D54.2 (A), D55.2 (A), D56.2 (A), D57.2 (A), D58.2 (A), D59.2 (A), D60.2 (A), D61.2 (A), D62.2 (A), D63.2 (A), D64.2 (A), D65.2 (A), D66.2 (A), D67.2 (A), D68.2 (A), D69.2 (A), D70.2 (A), D71.2 (A), D72.2 (A), D73.2 (A), D74.2 (A), D75.2 (A), D76.2 (A), D77.2 (A), D78.2 (A), D79.2 (A), D80.2 (A), D81.2 (A), D82.2 (A), D83.2 (A), D84.2 (A), D85.2 (A), D86.2 (A), D87.2 (A), D88.2 (A), D89.2 (A), D90.2 (A), D91.2 (A), D92.2 (A), D93.2 (A), D94.2 (A), D95.2 (A), D96.2 (A), D97.2 (A), D98.2 (A), D99.2 (A), D100.2 (A), D101.2 (A), D102.2 (A), D103.2 (A), D104.2 (A), D105.2 (A), D106.2 (A), D107.2 (A), D108.2 (A), D109.2 (A), D110.2 (A), D111.2 (A), D112.2 (A), D113.2 (A), D114.2 (A), D115.2 (A), D116.2 (A), D117.2 (A), D118.2 (A), D119.2 (A), D120.2 (A), D121.2 (A), D122.2 (A), D123.2 (A), D124.2 (A), D125.2 (A), D126.2 (A), D127.2 (A), D128.2 (A), D129.2 (A), D130.2 (A), D131.2 (A), D132.2 (A), D133.2 (A), D134.2 (A), D135.2 (A), D136.2 (A), D137.2 (A), D138.2 (A), D139.2 (A), D140.2 (A), D141.2 (A), D142.2 (A), D143.2 (A), D144.2 (A), D145.2 (A), D146.2 (A), D147.2 (A), D148.2 (A), D149.2 (A), D150.2 (A), D151.2 (A), D152.2 (A), D153.2 (A), D154.2 (A), D155.2 (A), D156.2 (A), D157.2 (A), D158.2 (A), D159.2 (A), D160.2 (A), D161.2 (A), D162.2 (A), D163.2 (A), D164.2 (A), D165.2 (A), D166.2 (A), D167.2 (A), D168.2 (A), D169.2 (A), D170.2 (A), D171.2 (A), D172.2 (A), D173.2 (A), D174.2 (A), D175.2 (A), D176.2 (A), D177.2 (A), D178.2 (A), D179.2 (A), D180.2 (A), D181.2 (A), D182.2 (A), D183.2 (A), D184.2 (A), D185.2 (A), D186.2 (A), D187.2 (A), D188.2 (A), D189.2 (A), D190.2 (A), D191.2 (A), J3.1, R7.1, R8.1, R9.1, R10.1, R22.1, R23.1, U2.40 (VCC), U2.43 (EN), U3.39 (ADDR1), U3.40 (VCC), U3.43 (EN), U4.38 (ADDR0), U4.40 (VCC), U4.43 (EN), U5.38 (ADDR0), U5.39 (ADDR1), U5.40 (VCC), U5.43 (EN), U7.38 (ADDR0), U7.40 (VCC), U7.43 (EN), U8.40 (VCC), U8.43 (EN)
abus0: D69.1 (K), U2.1 (OUT0)
abus1: D76.1 (K), U2.2 (OUT1)
abus2: D91.1 (K), U2.3 (OUT2)
abus3: D101.1 (K), U2.4 (OUT3)
abus4: D92.1 (K), U2.5 (OUT4)
abus5: D75.1 (K), U2.6 (OUT5)
abus6: D85.1 (K), U2.7 (OUT6)
abus7: D70.1 (K), U2.8 (OUT7)
abus8: D79.1 (K), U2.9 (OUT8)
abus9: D93.1 (K), U2.10 (OUT9)
abus10: D103.1 (K), U2.11 (OUT10)
abus11: D95.1 (K), U2.12 (OUT11)
abus12: D77.1 (K), U2.13 (OUT12)
abus13: D87.1 (K), U2.14 (OUT13)
abus14: D71.1 (K), U2.15 (OUT14)
abus15: D80.1 (K), U2.16 (OUT15)
abus16: D94.1 (K), U2.17 (OUT16)
abus17: D104.1 (K), U2.18 (OUT17)
abus18: D96.1 (K), U2.19 (OUT18)
abus19: D78.1 (K), U2.20 (OUT19)
abus20: D88.1 (K), U2.21 (OUT20)
abus21: D72.1 (K), U2.22 (OUT21)
abus22: D83.1 (K), U2.23 (OUT22)
abus23: D97.1 (K), U2.24 (OUT23)
abus24: D105.1 (K), U2.25 (OUT24)
abus25: D99.1 (K), U2.26 (OUT25)
abus26: D81.1 (K), U2.27 (OUT26)
abus27: D89.1 (K), U2.28 (OUT27)
abus28: D73.1 (K), U2.29 (OUT28)
abus29: D84.1 (K), U2.30 (OUT29)
abus30: D98.1 (K), U2.31 (OUT30)
abus31: D106.1 (K), U2.32 (OUT31)
abus32: D100.1 (K), U2.33 (OUT32)
abus33: D82.1 (K), U2.34 (OUT33)
abus34: D90.1 (K), U2.35 (OUT34)
bbus0: D111.1 (K), U4.1 (OUT0)
bbus1: D118.1 (K), U4.2 (OUT1)
bbus2: D133.1 (K), U4.3 (OUT2)
bbus3: D144.1 (K), U4.4 (OUT3)
bbus4: D134.1 (K), U4.5 (OUT4)
bbus5: D117.1 (K), U4.6 (OUT5)
bbus6: D128.1 (K), U4.7 (OUT6)
bbus7: D113.1 (K), U4.8 (OUT7)
bbus8: D121.1 (K), U4.9 (OUT8)
bbus9: D135.1 (K), U4.10 (OUT9)
bbus10: D145.1 (K), U4.11 (OUT10)
bbus11: D137.1 (K), U4.12 (OUT11)
bbus12: D119.1 (K), U4.13 (OUT12)
bbus13: D129.1 (K), U4.14 (OUT13)
bbus14: D114.1 (K), U4.15 (OUT14)
bbus15: D122.1 (K), U4.16 (OUT15)
bbus16: D136.1 (K), U4.17 (OUT16)
bbus17: D146.1 (K), U4.18 (OUT17)
bbus18: D138.1 (K), U4.19 (OUT18)
bbus19: D120.1 (K), U4.20 (OUT19)
bbus20: D130.1 (K), U4.21 (OUT20)
bbus21: D115.1 (K), U4.22 (OUT21)
bbus22: D125.1 (K), U4.23 (OUT22)
bbus23: D139.1 (K), U4.24 (OUT23)
bbus24: D147.1 (K), U4.25 (OUT24)
bbus25: D141.1 (K), U4.26 (OUT25)
bbus26: D123.1 (K), U4.27 (OUT26)
bbus27: D131.1 (K), U4.28 (OUT27)
bbus28: D116.1 (K), U4.29 (OUT28)
bbus29: D126.1 (K), U4.30 (OUT29)
bbus30: D140.1 (K), U4.31 (OUT30)
bbus31: D148.1 (K), U4.32 (OUT31)
bbus32: D142.1 (K), U4.33 (OUT32)
bbus33: D124.1 (K), U4.34 (OUT33)
bbus34: D132.1 (K), U4.35 (OUT34)
cbus0: D154.1 (K), U3.1 (OUT0)
cbus1: D160.1 (K), U3.2 (OUT1)
cbus2: D175.1 (K), U3.3 (OUT2)
cbus3: D186.1 (K), U3.4 (OUT3)
cbus4: D177.1 (K), U3.5 (OUT4)
cbus5: D159.1 (K), U3.6 (OUT5)
cbus6: D170.1 (K), U3.7 (OUT6)
cbus7: D155.1 (K), U3.8 (OUT7)
cbus8: D164.1 (K), U3.9 (OUT8)
cbus9: D178.1 (K), U3.10 (OUT9)
cbus10: D187.1 (K), U3.11 (OUT10)
cbus11: D180.1 (K), U3.12 (OUT11)
cbus12: D161.1 (K), U3.13 (OUT12)
cbus13: D171.1 (K), U3.14 (OUT13)
cbus14: D156.1 (K), U3.15 (OUT14)
cbus15: D165.1 (K), U3.16 (OUT15)
cbus16: D179.1 (K), U3.17 (OUT16)
cbus17: D188.1 (K), U3.18 (OUT17)
cbus18: D181.1 (K), U3.19 (OUT18)
cbus19: D162.1 (K), U3.20 (OUT19)
cbus20: D172.1 (K), U3.21 (OUT20)
cbus21: D157.1 (K), U3.22 (OUT21)
cbus22: D168.1 (K), U3.23 (OUT22)
cbus23: D182.1 (K), U3.24 (OUT23)
cbus24: D189.1 (K), U3.25 (OUT24)
cbus25: D184.1 (K), U3.26 (OUT25)
cbus26: D166.1 (K), U3.27 (OUT26)
cbus27: D173.1 (K), U3.28 (OUT27)
cbus28: D158.1 (K), U3.29 (OUT28)
cbus29: D169.1 (K), U3.30 (OUT29)
cbus30: D183.1 (K), U3.31 (OUT30)
cbus31: D190.1 (K), U3.32 (OUT31)
cbus32: D185.1 (K), U3.33 (OUT32)
cbus33: D167.1 (K), U3.34 (OUT33)
cbus34: D174.1 (K), U3.35 (OUT34)
dbus0: D15.1 (K), U5.1 (OUT0)
dbus1: D19.1 (K), U5.2 (OUT1)
dbus2: D23.1 (K), U5.3 (OUT2)
dbus3: D27.1 (K), U5.4 (OUT3)
dbus4: D25.1 (K), U5.5 (OUT4)
dbus5: D17.1 (K), U5.6 (OUT5)
dbus6: D21.1 (K), U5.7 (OUT6)
dbus7: D16.1 (K), U5.8 (OUT7)
dbus8: D20.1 (K), U5.9 (OUT8)
dbus9: D24.1 (K), U5.10 (OUT9)
dbus10: D28.1 (K), U5.11 (OUT10)
dbus11: D26.1 (K), U5.12 (OUT11)
dbus12: D18.1 (K), U5.13 (OUT12)
dbus13: D22.1 (K), U5.14 (OUT13)
ebus0: D37.1 (K), U5.15 (OUT14)
ebus1: D43.1 (K), U5.16 (OUT15)
ebus2: D53.1 (K), U5.17 (OUT16)
ebus3: D61.1 (K), U5.18 (OUT17)
ebus4: D55.1 (K), U5.19 (OUT18)
ebus5: D41.1 (K), U5.20 (OUT19)
ebus6: D49.1 (K), U5.21 (OUT20)
ebus7: D38.1 (K), U5.22 (OUT21)
ebus8: D44.1 (K), U5.23 (OUT22)
ebus9: D54.1 (K), U5.24 (OUT23)
ebus10: D62.1 (K), U5.25 (OUT24)
ebus11: D56.1 (K), U5.26 (OUT25)
ebus12: D42.1 (K), U5.27 (OUT26)
ebus13: D50.1 (K), U5.28 (OUT27)
fbus0: D39.1 (K), U8.1 (OUT0)
fbus1: D47.1 (K), U8.2 (OUT1)
fbus2: D57.1 (K), U8.3 (OUT2)
fbus3: D63.1 (K), U8.4 (OUT3)
fbus4: D59.1 (K), U8.5 (OUT4)
fbus5: D45.1 (K), U8.6 (OUT5)
fbus6: D51.1 (K), U8.7 (OUT6)
fbus7: D40.1 (K), U8.8 (OUT7)
fbus8: D48.1 (K), U8.9 (OUT8)
fbus9: D58.1 (K), U8.10 (OUT9)
fbus10: D64.1 (K), U8.11 (OUT10)
fbus11: D60.1 (K), U8.12 (OUT11)
fbus12: D46.1 (K), U8.13 (OUT12)
fbus13: D52.1 (K), U8.14 (OUT13)
g0bus0: D3.1 (K), U5.29 (OUT28)
g0bus1: D10.1 (K), U5.30 (OUT29)
g0bus2: D4.1 (K), U5.31 (OUT30)
g0bus3: D7.1 (K), U5.32 (OUT31)
g0bus4: D13.1 (K), U5.33 (OUT32)
g0bus5: D12.1 (K), U5.34 (OUT33)
g0bus6: D11.1 (K), U5.35 (OUT34)
g0bus7: D14.1 (K), U5.36 (OUT35)
g1bus0: D5.1 (K), U8.15 (OUT14)
g1bus1: D8.1 (K), U8.16 (OUT15)
g1bus2: D9.1 (K), U8.17 (OUT16)
g1bus3: D6.1 (K), U8.18 (OUT17)
g2bus0: D29.1 (K), U8.19 (OUT18)
g2bus1: D33.1 (K), U8.20 (OUT19)
g2bus2: D34.1 (K), U8.21 (OUT20)
g2bus3: D30.1 (K), U8.22 (OUT21)
g3bus0: D31.1 (K), U8.23 (OUT22)
g3bus1: D35.1 (K), U8.24 (OUT23)
g3bus2: D36.1 (K), U8.25 (OUT24)
g3bus3: D32.1 (K), U8.26 (OUT25)
g4bus0: D65.1 (K), U7.9 (OUT8)
g4bus1: D66.1 (K), U7.10 (OUT9)
g4bus2: D67.1 (K), U7.11 (OUT10)
g4bus3: D68.1 (K), U7.12 (OUT11)
g5bus0: D107.1 (K), U7.1 (OUT0)
g5bus1: D108.1 (K), U7.2 (OUT1)
g5bus2: D109.1 (K), U7.3 (OUT2)
g5bus3: D110.1 (K), U7.4 (OUT3)
g6bus0: D149.1 (K), U7.5 (OUT4)
g6bus1: D150.1 (K), U7.6 (OUT5)
g6bus2: D151.1 (K), U7.7 (OUT6)
g6bus3: D152.1 (K), U7.8 (OUT7)
sabus0: D74.1 (K), U8.27 (OUT26)
sabus1: D86.1 (K), U8.28 (OUT27)
sabus2: D102.1 (K), U8.29 (OUT28)
sbbus0: D112.1 (K), U8.30 (OUT29)
sbbus1: D127.1 (K), U8.31 (OUT30)
sbbus2: D143.1 (K), U8.32 (OUT31)
scbus0: D153.1 (K), U8.33 (OUT32)
scbus1: D163.1 (K), U8.34 (OUT33)
scbus2: D176.1 (K), U8.35 (OUT34)

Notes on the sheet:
I2C Bus 1
LED Power Connector
Main I2C Bus
USB Micro-B
I2C Bus 0
DNP

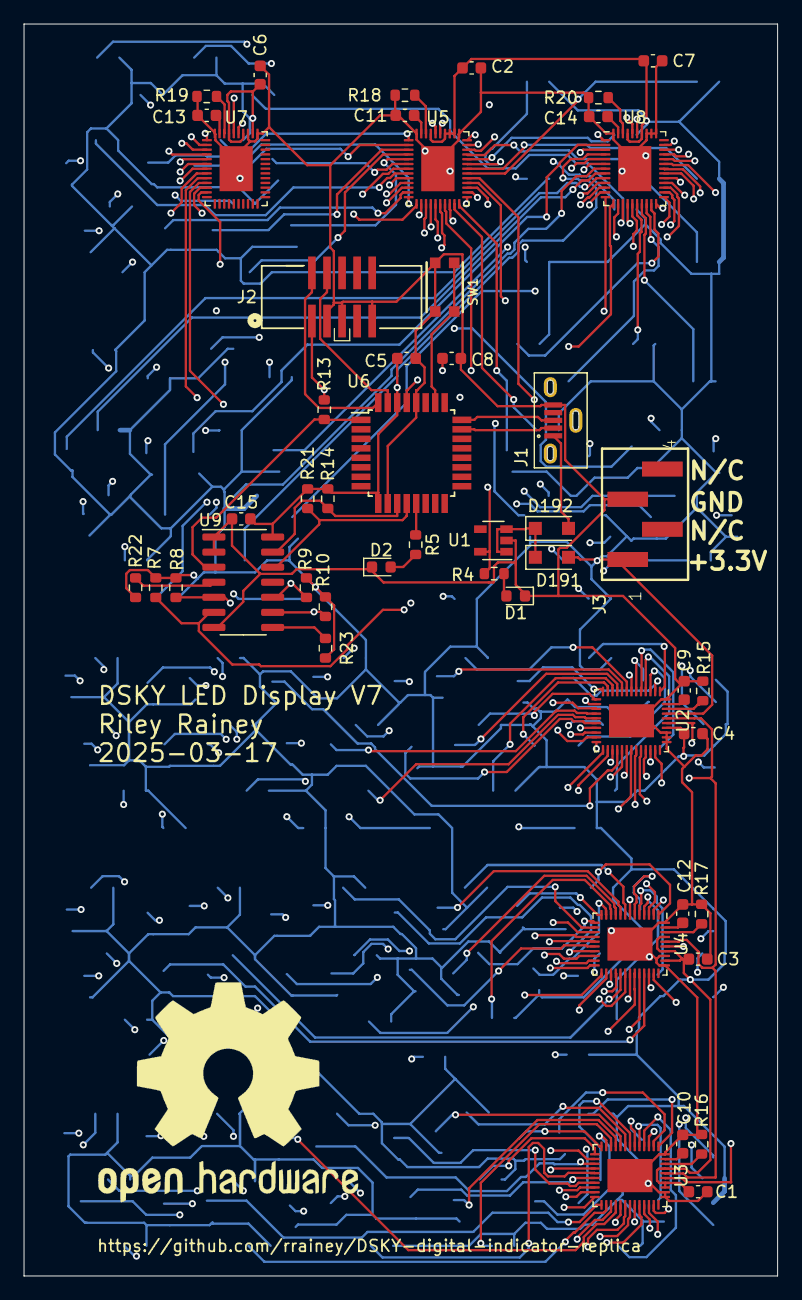
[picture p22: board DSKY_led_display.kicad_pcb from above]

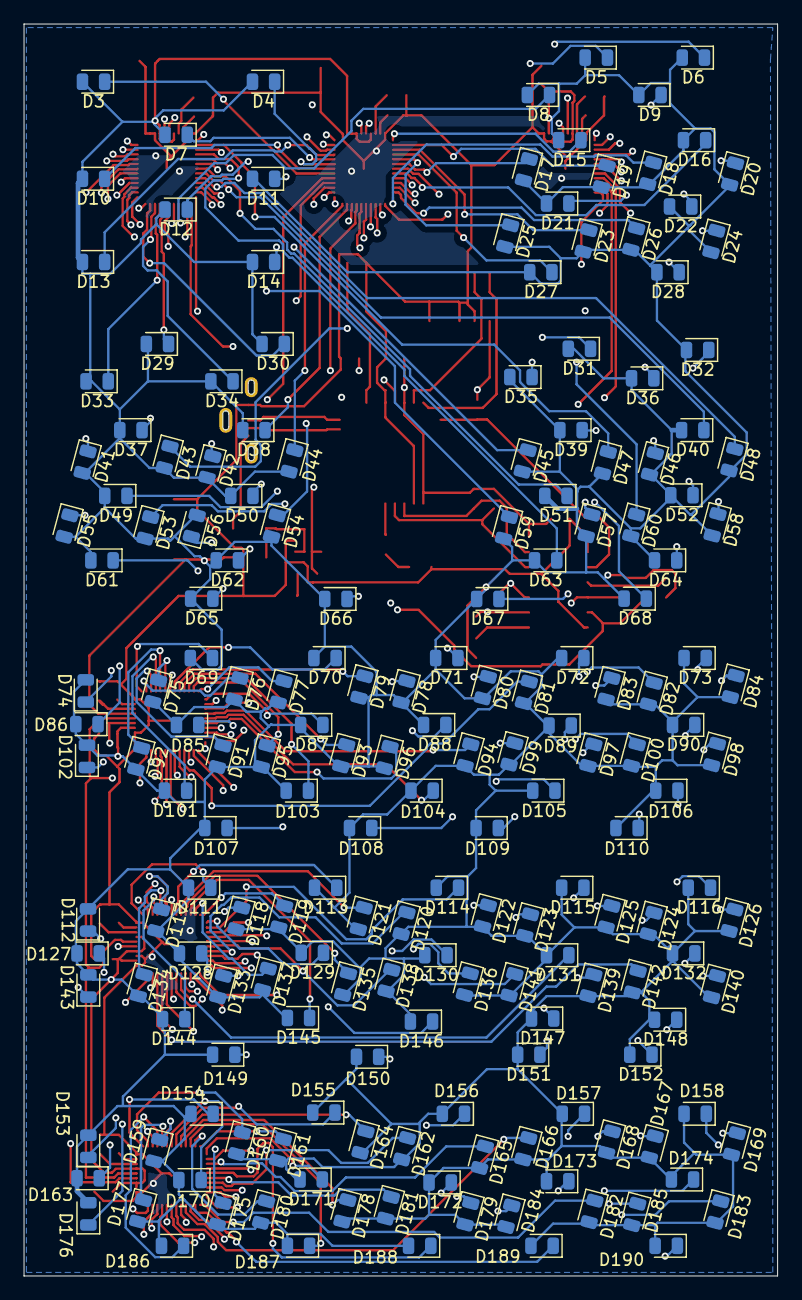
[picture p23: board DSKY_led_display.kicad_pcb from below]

Board: 4 copper layers, 63.5 x 105.5 mm, 237 parts (188 on the bottom side), 223 nets.

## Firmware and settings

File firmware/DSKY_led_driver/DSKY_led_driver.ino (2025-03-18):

/*
Copyright (c) 2021, Riley Rainey

Portions based on code supplied by Ben Krasnow
see https://github.com/benkrasnow/DSKY_EL_replica

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
THE SOFTWARE IS PROVIDED "AS IS", WITHOUT WARRANTY OF ANY KIND, EXPRESS OR
IMPLIED, INCLUDING BUT NOT LIMITED TO THE WARRANTIES OF MERCHANTABILITY,
FITNESS FOR A PARTICULAR PURPOSE AND NONINFRINGEMENT. IN NO EVENT SHALL THE
AUTHORS OR COPYRIGHT HOLDERS BE LIABLE FOR ANY CLAIM, DAMAGES OR OTHER
LIABILITY, WHETHER IN AN ACTION OF CONTRACT, TORT OR OTHERWISE, ARISING FROM,
OUT OF OR IN CONNECTION WITH THE SOFTWARE OR THE USE OR OTHER DEALINGS IN THE
SOFTWARE.
*/

#include <SPI.h>
#include <Arduino.h>
#include <Wire.h>
#include "wiring_private.h"

#include <SoftWire.h>
#include <AsyncDelay.h>

/*
 * DSKY LED Display Driver for V4 board
 * 
 * This board design includes six Texas Instruments LP5036 LED driver ICs, each capable of directly driving 36 LEDs.
 * LP5036 ICs are controlled via an I2C interface but only support four distinct I2C addresses. Since we're
 * using six chips, we group the LP5036 chips into two banks -- four on bank 0 and two on bank 1. We use a TI TCA9543A as an
 * I2C bank / channel selector.
 *
 * References: [1] TI TCA9543A I2C multiplexor data sheet https://www.ti.com/lit/ds/symlink/tca9543a.pdf?ts=1626710180580
 *             [2] https://www.ti.com/lit/ds/symlink/lp5036.pdf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
 */

 /*********************************************************************************************
  *  O P E R A T I O N   M O D E S
  * 
  *  Set the op_mode variable to one of the following values to select the desired operation mode.
  * 
  *  For testing, I prefer mode 1, which test each bank of digits and then illuminates each digit 
  *  in a predefined sequence.
  * 
  *  Mode 0 is normally what I set once testing is complete.
  * 
  **********************************************************************************************/

 int op_mode = 1; // 1 = boot in digit test mode: bank test; then illuminate one seven-segment 
                  //     digit at a time
                  // 2 = boot in segment test mode: illuminate one segment at a time sequentially,
                  //     and indicate the number via serial interface. Receiving any byte via serial
                  //     advances to next segment.
                  // 3 = boot in simulator mode.  Upon receiving a byte via USB serial interface,
                  //     cancel simulator mode and accept data via USB only.
                  // 0 = boot in normal operating mode -- the display will be driven by data received
                  //     via the USB serial interface.

/*
 * LED - Macro used to compress the addressing information for each discrete LED.
 * 
 * +--------------+-------------+--------------------------+
 * | bank(4-bits) | ic (2-bits) |   line (6-bits) [0..35]  |
 * +--------------+-------------+--------------------------+
 */

#define LED(bank,ic,line) (unsigned short)((line & 0x3F) | ((ic & 0x3) << 6) | ((bank & 0xF) << 8))

/*
 * An LED group is a set of discrete LEDs; it is identified with bank set to 0xf
 */
#define IS_GROUP  0xf
#define LED_GROUP(group) (unsigned short)(group | (IS_GROUP<<8))

/*
 * This value is used to mean no LED is assigned to this slot.
 */
#define EMPTY  LED_GROUP(63)

// Pin definitions (Arduino board definition largely derived from Trinket M0)

#define PIN_RED_LED        13
#define PIN_TCA9543A_RESET 7  // SAMD21 PA00

/**
 * I2C address for TCA9543A I2C Multiplexor IC
 */
#define TCAADDR 0x70

#define RESET_I2C_MUX_ON_BOOT 1

/**
 * I2C Addressing for the six LP5036 ICs
 * 
 * Mux Bank / I2C Address  / IC Name
 *      0        0x30          U2
 *      0        0x31          U4
 *      0        0x32          U3
 *      0        0x33          U5
 * 
 *      1        0x30          U8
 *      1        0x31          U7
 */

const char PACKET_START = '[';  //Uses this character to indicate start of packet when receiving data via USB serial link

/*
 * LED Group table
 * 
 * The segments of each digit have a single LED illuminating it.  For larger regions on the display, though, groups of LEDS are used.
 * The "group" table defines the discrete LEDs that comprise each group.
 */

#define LED_GROUP_SIZE 8
#define MAX_GROUPS     10

/*
 * List of Groups
 */
#define GROUP_COMP_ACTY 0
#define GROUP_PROG_LAMP 1
#define GROUP_VERB_LAMP 2
#define GROUP_NOUN_LAMP 3
#define GROUP_R1_BAR    4
#define GROUP_R2_BAR    5
#define GROUP_R3_BAR    6
#define GROUP_R1_PLUS   7
#define GROUP_R2_PLUS   8
#define GROUP_R3_PLUS   9

/*
 * Group to discrete LED mapping
 */

const uint16_t group[MAX_GROUPS][LED_GROUP_SIZE] =
  { 
    { LED(0,3,28), LED(0,3,29), LED(0,3,30), LED(0,3,31), LED(0,3,32), LED(0,3,33), LED(0,3,34), LED(0,3,35) },
    { LED(1,0,14), LED(1,0,15), LED(1,0,16), LED(1,0,17), EMPTY, EMPTY, EMPTY, EMPTY },
    { LED(1,0,18), LED(1,0,19), LED(1,0,20), LED(1,0,21), EMPTY, EMPTY, EMPTY, EMPTY },
    { LED(1,0,22), LED(1,0,23), LED(1,0,24), LED(1,0,25), EMPTY, EMPTY, EMPTY, EMPTY },
    { LED(1,1,0), LED(1,1,1), LED(1,1,2), LED(1,1,3), EMPTY, EMPTY, EMPTY, EMPTY },
    { LED(1,1,4), LED(1,1,5), LED(1,1,6), LED(1,1,7), EMPTY, EMPTY, EMPTY, EMPTY },
    { LED(1,1,8), LED(1,1,9), LED(1,1,10), LED(1,1,11), EMPTY, EMPTY, EMPTY, EMPTY },
    { LED(1,0,26), LED(1,0,28), EMPTY, EMPTY, EMPTY, EMPTY, EMPTY, EMPTY },
    { LED(1,0,29), LED(1,0,31), EMPTY, EMPTY, EMPTY, EMPTY, EMPTY, EMPTY },
    { LED(1,0,32), LED(1,0,34), EMPTY, EMPTY, EMPTY, EMPTY, EMPTY, EMPTY }
  };

/*
 * Ben Krasnow's original driver used this table to map logical DSKY display digits to the actual EL Driver lines to
 * be driven to illuminate each segment.  We do something similar here, although this table references the address
 * of both single LEDs and in some cases groups of LEDs that are illuminated as a single unit.
 */

#define TOTAL_DISP_CHAR 25
#define NUM_SEGMENTS 7
#define NUM_PIXELS (TOTAL_DISP_CHAR*NUM_SEGMENTS)

const uint16_t seg_lookup[TOTAL_DISP_CHAR][NUM_SEGMENTS] =
    {     // a, b, c, d, e, f, g
        { LED(0,3,0), LED(0,3,1), LED(0,3,2), LED(0,3,3), LED(0,3,4), LED(0,3,5), LED(0,3,6) },
        { LED(0,3,7), LED(0,3,8), LED(0,3,9), LED(0,3,10), LED(0,3,11), LED(0,3,12), LED(0,3,13) }, 
        { LED(0,3,14), LED(0,3,15), LED(0,3,16), LED(0,3,17), LED(0,3,18), LED(0,3,19), LED(0,3,20) }, 
        { LED(0,3,21), LED(0,3,22), LED(0,3,23), LED(0,3,24), LED(0,3,25), LED(0,3,26), LED(0,3,27) }, 
        { LED(1,0,0), LED(1,0,1), LED(1,0,2), LED(1,0,3), LED(1,0,4), LED(1,0,5), LED(1,0,6) },
        { LED(1,0,7), LED(1,0,8), LED(1,0,9), LED(1,0,10), LED(1,0,11), LED(1,0,12), LED(1,0,13) }, 
        // R1 (upper) Sign Digits
        { EMPTY, LED_GROUP(GROUP_R1_PLUS), EMPTY, EMPTY, EMPTY, EMPTY, LED(1,0,27) },
        //{158,98,158,158,158,158,104},        //6 upper plus/minus  (it's not efficient to use a whole byte for just plus/minus, but creates character consistency and more readable code. The seven-seg decoder function accepts '+' and '-'  
        // R1 (upper) 5 digits
        { LED(0,0,0), LED(0,0,1), LED(0,0,2), LED(0,0,3), LED(0,0,4), LED(0,0,5), LED(0,0,6) },
        { LED(0,0,7), LED(0,0,8), LED(0,0,9), LED(0,0,10), LED(0,0,11), LED(0,0,12), LED(0,0,13) },
        { LED(0,0,14), LED(0,0,15), LED(0,0,16), LED(0,0,17), LED(0,0,18), LED(0,0,19), LED(0,0,20) }, 
        { LED(0,0,21), LED(0,0,22), LED(0,0,23), LED(0,0,24), LED(0,0,25), LED(0,0,26), LED(0,0,27) }, 
        { LED(0,0,28), LED(0,0,29), LED(0,0,30), LED(0,0,31), LED(0,0,32), LED(0,0,33), LED(0,0,34) }, 
        //{158,88,158,158,158,158,89},  //12   middle  plus/minus
        { EMPTY, LED_GROUP(GROUP_R2_PLUS), EMPTY, EMPTY, EMPTY, EMPTY, LED(1,0,30) },
        // R2 (middle) digits
        { LED(0,1,0), LED(0,1,1), LED(0,1,2), LED(0,1,3), LED(0,1,4), LED(0,1,5), LED(0,1,6) },
        { LED(0,1,7), LED(0,1,8), LED(0,1,9), LED(0,1,10), LED(0,1,11), LED(0,1,12), LED(0,1,13) },
        { LED(0,1,14), LED(0,1,15), LED(0,1,16), LED(0,1,17), LED(0,1,18), LED(0,1,19), LED(0,1,20) }, 
        { LED(0,1,21), LED(0,1,22), LED(0,1,23), LED(0,1,24), LED(0,1,25), LED(0,1,26), LED(0,1,27) }, 
        { LED(0,1,28), LED(0,1,29), LED(0,1,30), LED(0,1,31), LED(0,1,32), LED(0,1,33), LED(0,1,34) },
        { EMPTY, LED_GROUP(GROUP_R3_PLUS), EMPTY, EMPTY, EMPTY, EMPTY, LED(1,0,33) }, 
        //{158,29,158,158,158,158,28},         //18  lower  plus /minus
        // R3 (lower) digits
        { LED(0,2,0), LED(0,2,1), LED(0,2,2), LED(0,2,3), LED(0,2,4), LED(0,2,5), LED(0,2,6) },
        { LED(0,2,7), LED(0,2,8), LED(0,2,9), LED(0,2,10), LED(0,2,11), LED(0,2,12), LED(0,2,13) },
        { LED(0,2,14), LED(0,2,15), LED(0,2,16), LED(0,2,17), LED(0,2,18), LED(0,2,19), LED(0,2,20) }, 
        { LED(0,2,21), LED(0,2,22), LED(0,2,23), LED(0,2,24), LED(0,2,25), LED(0,2,26), LED(0,2,27) }, 
        { LED(0,2,28), LED(0,2,29), LED(0,2,30), LED(0,2,31), LED(0,2,32), LED(0,2,33), LED(0,2,34) },  
        { LED_GROUP(GROUP_COMP_ACTY), 
          LED_GROUP(GROUP_PROG_LAMP), 
          LED_GROUP(GROUP_VERB_LAMP), 
          LED_GROUP(GROUP_NOUN_LAMP), 
          LED_GROUP(GROUP_R1_BAR), 
          LED_GROUP(GROUP_R2_BAR), 
          LED_GROUP(GROUP_R3_BAR) }           
        //{166,129,167,138,109,75,164}  //24    special character for boxes and bars on display.  top-to-bottom, left-to-right:  a=COMP ACTY, b=PROG, c=VERB, d=NOUN, e=upper line, f=middle line, g=lower line
    };

/*
 * LP5036 Register Map 
 * accesed via I2C interface
 * see https://www.ti.com/lit/ds/symlink/lp5036.pdf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
 */
#define DEVICE_CONFIG0      0x00
#define DEVICE_CONFIG1      0x01
#define LED_CONFIG0         0x02
#define LED_CONFIG1         0x03
#define BANK_BRIGHTNESS     0x04
#define LED_BRIGHTNESS_BASE 0x08
#define OUT_COLOR_BASE      0x14
#define RESET               0x38

#define CHIP_EN             0b01000000  // bit on DEVICE_CONFIG0

#define BANK_COUNT          12  // count of LED banks on one IC

#define LED_LINE_COUNT      36  // count of distinct lines on one IC

/*
 * Brightness value sent to the LP5036 chips to illuminate an LED (range 0x00..0xff)
 * On the V2 through V4 board, 0xff corresponds to a 20mA current
 */
unsigned char global_brightness = 0x20;

unsigned char led_brightness = 0x20;

int test_on_ms = 300;
int test_off_ms = 50;

/*
 * Silkscreen label for each LP5036 IC on the physical board
 */
const char * ic_names[] = { "U2", "U4", "U3", "U5", "U8", "U7", "UNK1", "UNK2" };

//TwoWire myWire(&sercom1, PIN_WIRE_SCL, PIN_WIRE_SDA);

SoftWire myWire(SDA, SCL);
char swTxBuffer[64];
char swRxBuffer[16];

void setup() 
{

  pinMode(PIN_TCA9543A_RESET, OUTPUT);
  digitalWrite(PIN_TCA9543A_RESET, HIGH);

  // Red LED on to indicate initialization has started
  pinMode(PIN_RED_LED, OUTPUT);
  digitalWrite(PIN_RED_LED, HIGH);

  // wait max 10 seconds for Serial to connect in any test mode
  uint32_t start_ms = millis();
  uint32_t wait_ms = op_mode == 0 ? 120000 : 10000;
  while (!Serial && (millis()-start_ms < wait_ms)) delay(10);
  delay(500);

  // Red LED off to indicate we have a USB serial connection
  digitalWrite(PIN_RED_LED, LOW);

  // Start I2C
  //myWire.begin();

  myWire.setTxBuffer(swTxBuffer, sizeof(swTxBuffer));
  myWire.setRxBuffer(swRxBuffer, sizeof(swRxBuffer));
  myWire.setClock( 100000 ); // normal mode (100K)
  myWire.setTimeout( 500 );
  myWire.begin();

  // Start USB Serial
  Serial.begin(115200);
  Serial.println("\nLED Driver Ready\n");

  /*
   * Force a hardware reset on the I2C multiplexor?
   */

  if ( RESET_I2C_MUX_ON_BOOT == 1 ) {
    delay(1);
    digitalWrite(PIN_TCA9543A_RESET, LOW);
    delay(1); // datasheet says 500ns minimum
    digitalWrite(PIN_TCA9543A_RESET, HIGH);
    delay(1); // datasheet says "0ns"
  }

  verifyTCAMux();

  // Enable LP5036 ICs
  configureDriverIC(0,0);
  configureDriverIC(0,1);
  configureDriverIC(0,2);
  configureDriverIC(0,3);
  configureDriverIC(1,0);
  configureDriverIC(1,1);

  /*
   * These next two are present on a V4 board
   * however trying to initialize them will help debug
   * PCB issues.
   */
  configureDriverIC(1,2);
  configureDriverIC(1,3);

  delay(50);

  verifyDriverIC(0,0);
  verifyDriverIC(0,1);
  verifyDriverIC(0,2);
  verifyDriverIC(0,3);
  verifyDriverIC(1,0);
  verifyDriverIC(1,1);

  /*
   * These next are not be present on a V4 board
   * however trying to initialize them will help debug
   * PCB issues.
   */
  verifyDriverIC(1,2);
  verifyDriverIC(1,3);
  
}

void verifyTCAMux()
{
  int verified = 0;
  
  selectI2CChannel (0);

  myWire.requestFrom(TCAADDR, 1);

  while (myWire.available()) {
    char c = myWire.read();
    if ((c & 3) == 1) {
      verified |= 1;
    }
  }

  selectI2CChannel (1);

  myWire.requestFrom(TCAADDR, 1);

  while (myWire.available()) {
    char c = myWire.read();
    if ((c & 3) == 2) {
      verified |= 2;
    }
  }

  Serial.print("USB Mux IC test ");
  Serial.print((verified == 3) ? "passed " : "failed ");
  Serial.println();
}

void configureDriverIC(int bank, int ic)
{
  int ic_addr = 0x30 | ic;
  selectI2CChannel (bank);
  myWire.beginTransmission(ic_addr);
  myWire.write((unsigned char) DEVICE_CONFIG0 );
  myWire.write((unsigned char) CHIP_EN );
  myWire.endTransmission();

  // Set Banks 0-7 to independent control mode
  myWire.beginTransmission(ic_addr);
  myWire.write((unsigned char) LED_CONFIG0);
  myWire.write(0x00);                 
  myWire.endTransmission();

  // Set banks 8-11 to independent control mode
  myWire.beginTransmission(ic_addr);
  myWire.write((unsigned char) LED_CONFIG1);
  myWire.write(0x00);                 
  myWire.endTransmission();

  // Global Bank Brightness (0-255)
  myWire.beginTransmission(ic_addr);
  myWire.write((unsigned char) BANK_BRIGHTNESS);
  myWire.write(global_brightness);          // was F0       
  myWire.endTransmission();

  // All LEDs "on"
  int i;
  for(i=0; i<LED_LINE_COUNT; ++i) {
    myWire.beginTransmission(ic_addr);
    myWire.write((unsigned char) OUT_COLOR_BASE+i);
    myWire.write(global_brightness);                 
    myWire.endTransmission();
  }
  delay(1000);

  // All LEDs "off"
  for(i=0; i<LED_LINE_COUNT; ++i) {
    myWire.beginTransmission(ic_addr);
    myWire.write((unsigned char) OUT_COLOR_BASE+i);
    myWire.write(0);                 
    myWire.endTransmission();
  }
}

void verifyDriverIC(int bank, int ic)
{
  int ic_addr = 0x30 | ic;
  selectI2CChannel ( bank );
  
  myWire.beginTransmission(ic_addr);
  myWire.write((unsigned char) DEVICE_CONFIG0 );
  myWire.endTransmission();

  myWire.requestFrom(ic_addr, 1);

  while (myWire.available()) {
    char c = myWire.read();
    Serial.print("LP5036 ");
    Serial.print(ic_names[ic + bank*4]);
    Serial.print(" ");
    Serial.print(c & CHIP_EN ? "enabled" : "not enabled");
    Serial.println();
  }

}

void setLEDState( uint16_t lamp, boolean state) {
 
  int bank = lamp >> 8;
  int ic = (lamp >> 6) & 0x3;
  int line = lamp & 0x3f;

  // LED Group?
  if (bank == IS_GROUP) {
    
    // Not "EMPTY" group? activate all LEDs in the group
    if (line != 0x3f) {
      for (int i=0; i<LED_GROUP_SIZE; ++i) {
        uint16_t led = group[line][i];
        if (led != EMPTY) {
          setLEDState( led, state );
        }
      }
    }
  }
  else {
    selectI2CChannel( bank );
    int ic_addr = 0x30 | ic;
    myWire.beginTransmission(ic_addr);
    myWire.write((unsigned char) OUT_COLOR_BASE+line);
    myWire.write(state ? led_brightness : 0);                 
    myWire.endTransmission();
  }
}
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
void loop() {
  
  static int char_pos = 0;
  static int i, j;
  
  //only used for op_mode 3
  static unsigned long ProgTimer, NounTimer, VerbTimer, angTimer;
  static float tmpangle = 1.4;
  static int NounVal, VerbVal, ProgVal,TopVal, MidVal, BotVal;
  static int SpecVal = 8;
  static char tmpStr[] = "123456789123456789123456789";

  switch (op_mode) {
  case 1:

    for (i=0; i<TOTAL_DISP_CHAR; ++i) {
      const uint16_t *p;
      p = &seg_lookup[i][0];
      for (j=0; j<NUM_SEGMENTS; j++) {
        setLEDState(*(p+j), true);
      }

      int k = i-1;
      if (k < 0) {
        k = TOTAL_DISP_CHAR - 1;
      }
      p = &seg_lookup[k][0];
      for (j=0; j<NUM_SEGMENTS; j++) {
        setLEDState(*(p+j), false);
      }

      delay(1000);
    }
    break;

  case 2:
    
    for (i = 0; i<NUM_PIXELS; i++) {

      int m0, m1;
      int j = i-1;
      if (i == 0) {
        j = NUM_PIXELS - 1;
      }

      m0 = i % 7;
      m1 = i / 7;
      setLEDState( seg_lookup[m1][m0], true);

      m0 = j % 7;
      m1 = j / 7;
      setLEDState( seg_lookup[m1][m0], false);

      delay(300);
     
      //Serial.println(i);
      //while(!Serial.available());
      //Serial.read();
    }
    break;

  case 3:
    if (millis() - ProgTimer > 1000)
        {
          ProgVal = (ProgVal > 99) ? 0 : ProgVal + 5;
          ProgTimer = millis();
        }
        
    if (millis() - NounTimer > 500)
        {
          NounVal = (NounVal > 99) ? 0 : NounVal + 2;
          NounTimer = millis();
        }
      
    if (millis() - VerbTimer > 100)
        {
          VerbVal = (VerbVal > 99) ? 0 : VerbVal + 1;
           VerbTimer = millis();
        }
          
          
    if( millis() - angTimer > 70)
        {
          tmpangle = (tmpangle > 6.283) ? 0 : tmpangle + 0.001;
          angTimer = millis();
        }
        
      
     TopVal = (sin(tmpangle) * 100000.0);
     MidVal = (cos(tmpangle) * 100000.0);

    //TopVal = 55555;
    //MidVal = -12345;
    //BotVal = 0;

     DSKY_format_2dig(tmpStr, ProgVal);
     DSKY_format_2dig(tmpStr+2, VerbVal);
     DSKY_format_2dig(tmpStr+4, NounVal);
     DSKY_format_5dig(tmpStr+6, TopVal);
     DSKY_format_5dig(tmpStr+12, MidVal);
     DSKY_format_5dig(tmpStr+18, BotVal); 
     tmpStr[24] = '8';
          
      for(i = 0; i<TOTAL_DISP_CHAR;i++)
        {
          DSKY_set_char(i,tmpStr[i],global_brightness);
        }
    
    if (Serial.available())
      {
        op_mode = 0;
      }
    delay(10);
    break;

  case 0:

    /*
     * op_mode 0 is the normal mode for processing directives from 
     * the USB serial interface
     */
    while(Serial.available()) {
      
      char c = Serial.read();
      if (c == PACKET_START) {
        char_pos = 0;
      }
      else {  
        DSKY_set_char( char_pos,c, led_brightness );
        char_pos = (++char_pos == TOTAL_DISP_CHAR) ? 0 : char_pos;
        op_mode = 0;
      }
      
    }

    delay(2);
    break;
  }
}

/**
 * TCA I2C Channel Select
 * 
 * i - Select Channel 0 or 1
 * See reference [1], page 15
 */
static uint8_t curChannel = 255;

void selectI2CChannel(uint8_t i) {

  int result;
  
  if (i > 1) return;

  // Channel not what we already have previously selected? Change it
  
  if (i != curChannel) {
 
    myWire.beginTransmission(TCAADDR);

    // 0x01 == enable i2c channel 0
    // 0x02 == enable i2c channel 1
    
    myWire.write ((uint8_t) (1 << i));

    result = myWire.endTransmission();

    if (result != 0) {
      Serial.print("selectI2CChannel endTransmission; result = "); Serial.println(result);
    }
    else {
      curChannel = i;
    }
  }
}

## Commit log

2021-01-16 Import pcb folder
    [DSKY_led_display.kicad_pcb, DSKY_led_display.sch]
2021-01-16 validate pcb project is accessible from a second dev box
    [DSKY_led_display.sch]
2021-01-16 Add Fusion 360 assets
    [LED-light-guide.f3d, LED-light-guide.step]
2021-01-17 Update README to include PCB status
2021-01-27 V2 pcb as-ordered for testing
    [DSKY_led_display.kicad_pcb, DSKY_led_display.sch]
2021-02-25 V3 board
    [DSKY_led_display.kicad_pcb, DSKY_led_display.sch, DSKY_led_display_bom.csv]
2021-02-28 add prototype driver
2021-02-28 Add PCB fabrication notes
2021-07-20 starter updates for V3 board
2021-08-01 V4 board
    Version 4 of the PCB
    [DSKY_led_display.kicad_pcb, DSKY_led_display.sch, DSKY_led_display1.kicad_pcb]
2021-08-01 schematic PDF update
2021-08-18 intermediate version for V4 board
2021-08-25 fix issue with leftmost digit segment - 'c' digit coded incorrectly
    [DSKY_led_driver.ino]
2021-08-25 driver cleanup
2023-01-24 V4 PCB update
    [DSKY_led_display-B_Cu.gbr, DSKY_led_display-B_Mask.gbr, DSKY_led_display-B_Paste.gbr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]
2025-03-17 V7 PCB fixes placement of D56 LED -- it was reversed.
    [DSKY_led_display.csv, DSKY_led_display.kicad_pcb, DSKY_led_display.kicad_sch]
2025-03-17 V7 Gerbers and placement file - D56 placement was reversed in V6; corrected here
    [DSKY_led_display-B_Cu.gbr, DSKY_led_display-B_Mask.gbr, DSKY_led_display-B_Paste.gbr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]
2025-03-17 Update owing to KiCad V7 being fussier about bus definitions
    [DSKY_led_display-B_Cu.gbr, DSKY_led_display-B_Mask.gbr, DSKY_led_display-B_Paste.gbr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]
2025-03-17 Add some notes for V7 of the PCB
2025-03-17 Update PCB documentation
2025-03-17 Minor updates to the Arduino-based driver firmware.
2025-04-01 V6 and V7 PCB
    [1051330001.stp, 3221-10-0300-00 3D.STP, DSKY_led_display.kicad_pcb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]
2025-04-02 updated models including new light guide adapter
    [Body.step, PCB to Light-guide adapter.step, Retainer.step]
2025-04-03 update model and video
    [Body.step]
2025-04-05 Add SIngle Power Source mod notes
    [DSKY_led_display.kicad_sch, DSKY_led_display1.kicad_pcb]
2025-04-06 update notes
    [DSKY_led_display.kicad_sch]

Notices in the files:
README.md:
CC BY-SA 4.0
